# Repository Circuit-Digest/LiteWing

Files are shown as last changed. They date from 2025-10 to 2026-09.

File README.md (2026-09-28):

## LiteWing
image_tooltip
LiteWing is a compact, WiFi-controlled drone based on the ESP32-S3 microcontroller. Designed for hobbyists, makers, and engineers, LiteWing offers a simple yet powerful platform for drone experimentation and development. It is an open-hardware project, making it easy to modify and expand. Whether you're new to drones or an experienced developer looking to create custom flight applications, LiteWing provides an accessible and affordable way to explore drone technology. Unlike traditional drones that require proprietary controllers, LiteWing connects to your smartphone, allowing for an intuitive flying experience without additional hardware.

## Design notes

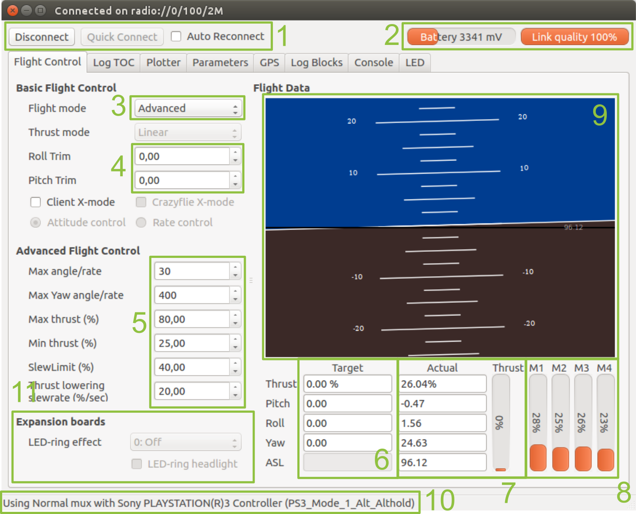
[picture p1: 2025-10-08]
Python-Scripts/crazyflie-clients-python/docs/images/cfclient_overview.png

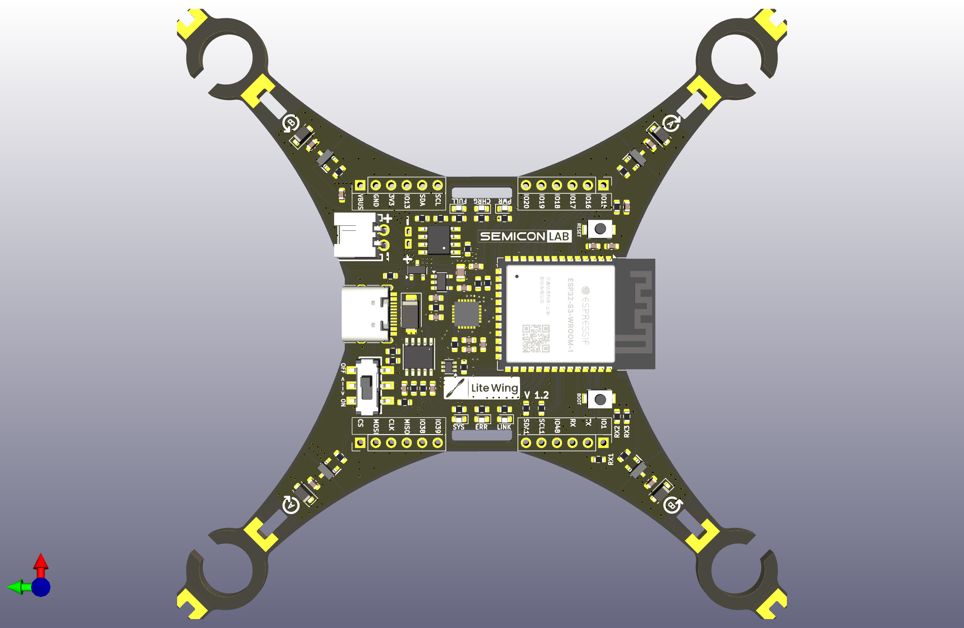
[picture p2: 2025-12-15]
hardware/LieWingV2.6.C/LieWingV2.6.C Front.png

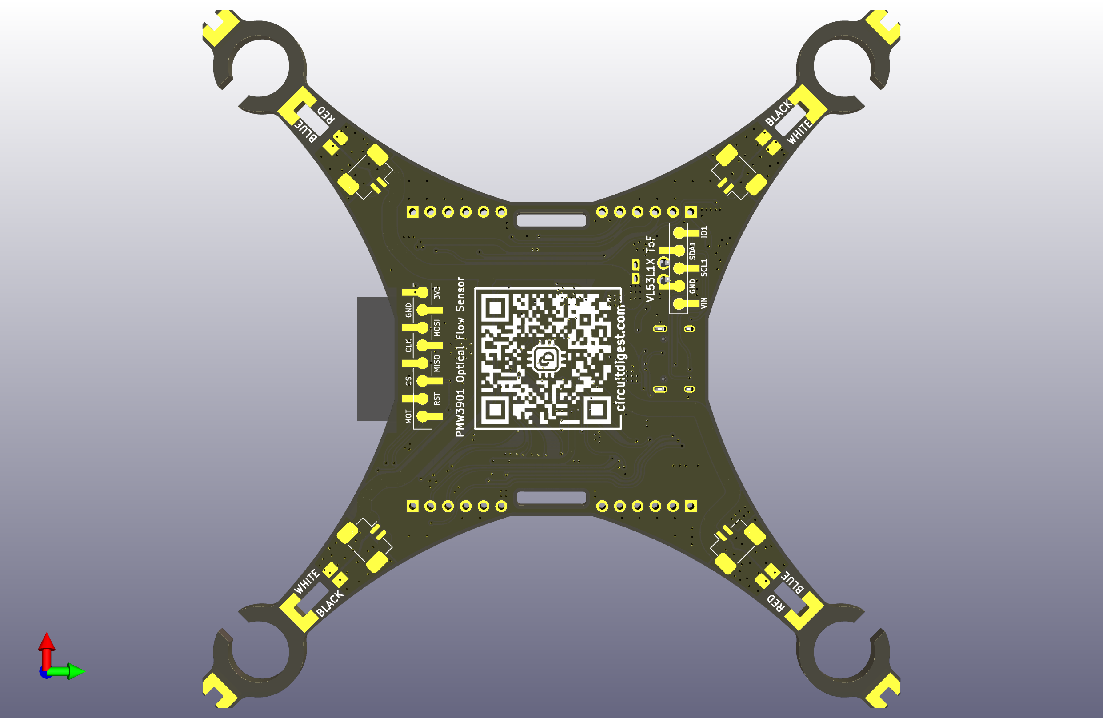
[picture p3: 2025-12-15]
hardware/LieWingV2.6.C/LieWingV2.6.C Back.png

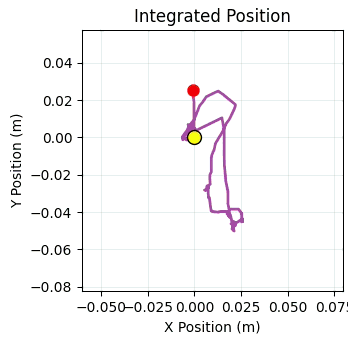
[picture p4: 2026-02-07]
Python-Scripts/Flight_Positioning_Module/LiteWing-Drone-Flight-Positioning-Module-Optical-Position-Plot.gif

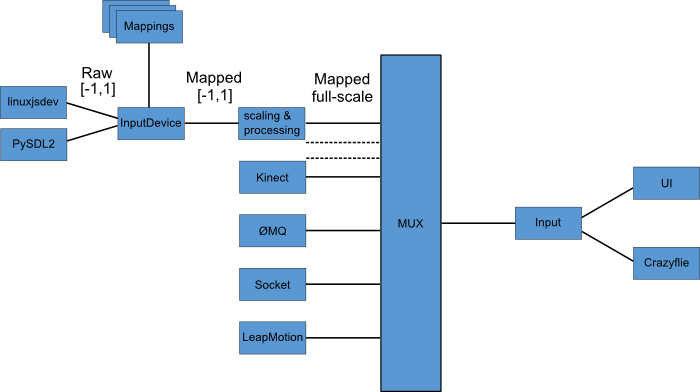
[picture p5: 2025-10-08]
Python-Scripts/crazyflie-clients-python/docs/images/input-arch-mux.png

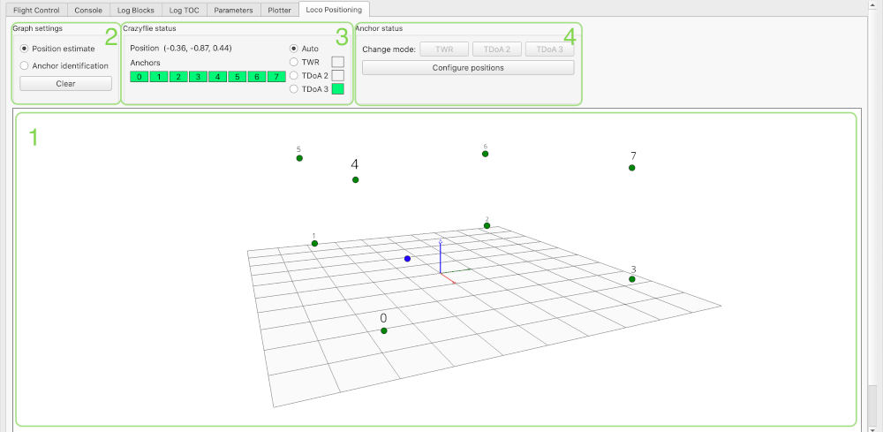
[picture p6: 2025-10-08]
Python-Scripts/crazyflie-clients-python/docs/images/cfclient_position_estimate.png

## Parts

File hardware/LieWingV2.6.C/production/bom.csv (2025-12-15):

Designator | Footprint | Quantity | Value | LCSC Part #
C1, C12, C4, C5 | 0603 | 4 | 10uF | C19702
C10, C13, C14, C6, C7, C8 | 0603 | 6 | 100nF | C14663
C11 | 0603 | 1 | 10nf | C57112
C15, C16, C17, C18 | 0603 | 4 | 1uF | C15849
C2 | 0603 | 1 | 470pF | C1620
C3 | 0805 | 1 | 2.2uF | C5448893
C9 | 0603 | 1 | 2.2nf | C1604
D1 | D_SMA | 1 | SS34 | C8678
D2, D3, D4, D5 | D_SOD-123F | 4 | 1N4148W | C81598
IC1 | SOIC127P600X175-9N | 1 | TP4056 | C20199357
J1 | USB_C_Receptacle_HRO_TYPE-C-31-M-12 | 1 | USB_C_Receptacle_USB2.0 | C2927038
J2 | CONN-TH_2P-P2.50_XH-2AW | 1 | JST XH 2P 2.50mm SMD Hoz | C33132
LED1, LED2, LED5 | 0603 | 3 | LED_Red | C2286
LED3, LED6 | 0603 | 2 | LED_Blue | C2288
LED4 | 0603 | 1 | LED_Green | C12065
R1, R2 | 0603 | 2 | 5.1K | C23186
R10, R11, R12, R13, R6, R7, R9 | 0603 | 7 | 1K | C21190
R14, R16, R17, R18, R19, R20, R21, R22, R23, R24, R25 | 0603 | 11 | 10k | C25804
R15 | 0603 | 1 | 4.7k | C23162
R26, R27, R3, R8 | 0603 | 4 | 100K | C25803
R28, R29, R30 | 0603 | 3 | 0R | C21189
R4 | 0603 | 1 | 470R | C23179
R5 | 0603 | 1 | 1.2K | C22765
SW1 | SW-SMD_MST22D18G2 | 1 | MST22D18G2_125 | C2906280
SW2, SW3 | Tactile 3x4x2mm TS-A010 | 2 | Tactile Switch 3x4x2 | C2874433
T1, T2, T3, T4 | SOT95P237X112-3N | 4 | IRLML6344TRPBF | C6285738
U1 | SOT-23 | 1 | AO3401A | C15127
U2 | SOT-23-5 | 1 | SPX3819M5-L-3-3/TR | C9055
U5 | ESSOP-10_3.9x4.9mm_P1.00mm | 1 | CH340K | C18208922
U6 | SOT-363_SC-70-6 | 1 | 2N27002DW | C5190214
U7 | MPU6050 | 1 | MPU-6050 | C24112
U8 | ESP32-S3-WROOM-1 | 1 | ESP32-S3-WROOM-1 | C2913198

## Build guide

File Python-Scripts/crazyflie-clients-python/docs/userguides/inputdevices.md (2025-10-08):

---
title: Input-devices for the Crazyflie client
page_id: inputdevices
---

The Crazyflie graphical control client needs an input-device (joystick)
with a minimum of 4 analogue axes to be able to pilot the Crazyflie. The
Playstation 3 controller is supported out of the box but the application
supports creating new configurations that uses other controllers. This
page details what controllers are supported out of the box, how to
create a new configurations and how to debug problems.

---

## Steps to get the controller working

Here\'s a few steps that you have to go though in order to get the
input-device working. If any of the steps are not working then the
input-device will not be usable for piloting the Crazyflie:

-   The input-device needs to be recognized by the host operating
    system. This means that it should be seen in the operating system
    and be usable in other applications or utilities.
-   When using the Crazyflie graphical control client you need at least
    the correct mappings for roll/pitch/yaw/thrust. This can be checked
    by opening the *Flight Data* tab. If the input-device is found and
    opened then you should see values in the *Target* fields for
    *Roll*,*Pitch*,*Yaw* and *Thrust*. Moving the analogue axis should
    show you output here. Make sure that you get the full span according
    to the settings on the left side of the tab. I.e if the setting for
    *Max roll/pitch* is 20 then you should be able to get from -20 to +
    20 in the target field (and the same for yaw and thrust). Also make
    sure that none of the axis interact (like moving roll will also move
    pitch).
-   If you aren\'t getting any output at all and you are using the
    Playstation 3 controller, then press the \"Playstation\" button in
    the middle on the controller once.
-   If the mappings are not correct in the previous point go to the menu
    *Input-device-\>Configure device mapping*, select the device you
    would like to configure and go though the configuration by clicking
    detect on each of the items in the dialog (everything has to be
    configured). Lastly enter the name of the configuration (without
    file extension) and press save. Now restart the application and try
    again.
-   It can happen be that another USB device other than your controller is recognized. Then it might be necessary to blacklist the USB device in the cfclient's config.json file. Check out [the config file explanation](/docs/development/dev_info_client.md#user-configuration-file)

---

## Input device overview

Below is a list of controllers and the status for different OSs. The
list is far from complete so if you have more info please edit or drop
us an email.

 | **Controller**    | **Linux USB** |   **Linux BT** |**Win XP USB**  | **Win XP BT**  |**Win7 USB**     |   **Win7 BT** |  **Win8 USB** |**Win10 USB** | **Win 11 USB** | **Mac OSX USB**  | **Mac OSX BT**|
|--|--|--|--|--|--|--|--|--|--|--|--|
 | Playstation 3 (or copy)  | Works  | Works |  Works |  Works | Works  | Works  | Works,  | Works | Not tested | Works   |  Works|
  Xbox 360 (or copy)   |  Works  | N/A  | Works    |   N/A    |   Works    |    N/A  |  Works | Works | Works| Not tested    |  Not tested|

### Playstation 3 controller

#### Linux using Bluetooth

[How to set up Sixaxis on
Ubuntu](https://help.ubuntu.com/community/Sixaxis) (tested on Ubuntu
13.10)

#### Win7 using USB

There\'s support for this using MotionJoy, **but** the mapping of the
axis is not the same as for Windows XP/Linux and has to be configured.
**TODO** Insert instructions for re-mapping.

[Video on how to get started with
MotionJoy](http://youtu.be/b2lUxNShIDs).

#### Win7 using Bluetooth

Should work using MotionJoy but this needs confirmation.

#### Win8 USB
[Instructions](http://www.wikihow.com/Set-Up-USB-Game-Controllers-on-Windows-8)

#### Mac OSX with Bluetooth

To pair the controller follow the steps outlined
[here](https://gist.github.com/statico/3172711). **TODO**: This
procedure is somewhat shaky. Figure out and add a solid set of steps
here.

**NOTE**: To shut down the controller you need to disconnect the
controller from OSX. This is easiest done if you enable in in System
Preferences -\> Bluetooth enable Show Bluetooth status in menu bar. From
the menu bar item you can easily disconnect it.

---

### Xbox 360 controller

#### Linux using USB

**INFO:** All modern Linux distribution now have a kernel driver for the x-box
gamepad. Thus it is unlikely the *xboxdrv* user-space driver is needed.

If you are having problems getting this to work the userspace driver
`xboxdrv` might be needed. It can be installed (on Ubuntu) by running:

    sudo apt-get install xboxdrv

And then started by running:

    sudo xboxdrv

More info about the `xboxdrv` is available
[here](https://xboxdrv.gitlab.io/).

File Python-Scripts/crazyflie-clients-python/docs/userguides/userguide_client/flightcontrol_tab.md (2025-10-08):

---
title: Flightcontrol Tab
page_id: flightcontrol_tab
sort_order: 1
---

The normal view used when flying is the one seen below.

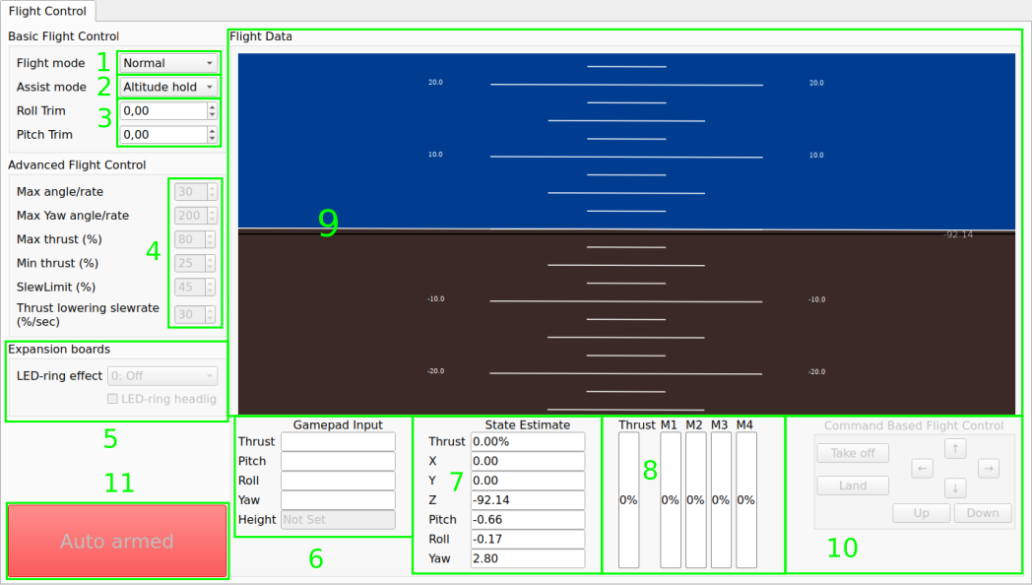
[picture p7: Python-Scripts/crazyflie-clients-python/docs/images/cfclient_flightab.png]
cfclient flighttab


1.  Flight mode selector (Normal and Advanced)
    * *Normal:* Recommended for beginners
    * *Advanced:* Will unlock flight settings in 3

2.  Assisted mode selection. The assisted mode is enabled when the assisted mode
    button is pressed on the Gamepad.
    * *Altitude hold*: Keeps the Crazyflie at its current altitude automatically. Thrust control becomes height velocity control.
    * *Position hold*: Keeps the Crazyflie at its current 3D position. Pitch/Roll/Thrust control becomes X/Y/Z velocity control.
    * *Height hold*: When activated, keeps the Crazyflie at 40cm above the ground. Thrust control becomes height velocity control. Requires a height sensor like the [Z-Ranger deck](https://www.bitcraze.io/products/z-ranger-deck-v2/).
    * *Hover*: When activated, keeps the Crazyflie at 40cm above the ground and tries to
    keep the position in X and Y as well. Thrust control becomes height velocity
    control. Requires a flow deck. Uses body-fixed coordinates.
3. Roll/pitch trim can be set either in the UI or using the controller (if the correct buttons are mapped).
    This will offset the input to the Crazyflie for correcting imbalance and reducing drift.
4. Advanced flight control settings are available if Advanced mode has been selected (settings are in %):
    * *Max angle:* Set the max roll/pitch angle allowed
    * *Max yaw rate:*Set the max yaw rate allowed
    * *Max thrust:* Set the max thrust allowed
    * *Min thrust:* Minimum thrust before 0 is sent to the Crazyflie
    * *Slew limit:* Set the percentage where the thrust is slew controlled (the thrust value lowering will be limited). This makes the Crazyflie a bit easier to fly for beginners
    * *Slew rate:* When the thrust is below the slew limit, this is the maximum rate of lowering the thrust
5. Settings for flight decks, currently the LED-ring effect and headlights can be set (if the ring is attached)
6. Target values sent from the client for controlling the Crazyflie
7. Actual values logged from the Crazyflie
8. Motor output on the Crazyflie
9. Horizon indicator
10. Command based flight control, allow controlled flight if, and only if, a positioning deck such as the [Flow deck](https://store.bitcraze.io/collections/decks/products/flow-deck-v2), the [Loco deck](https://store.bitcraze.io/collections/decks/products/loco-positioning-deck) or the [Lighthouse deck](https://store.bitcraze.io/collections/decks/products/lighthouse-positioning-deck) is present.
11. Arming/disarming button. Pressing this will send a arming or disarming event to the Crazyflie which will arm or disarm the system if this is possible. This button can also say "Auto arming" which indicates the crazyflie is configured to arm the system automatically if system checks have passed. More info in [crazyflie firmware arming documentation](https://www.bitcraze.io/documentation/repository/crazyflie-firmware/master/functional-areas/supervisor/arming/).

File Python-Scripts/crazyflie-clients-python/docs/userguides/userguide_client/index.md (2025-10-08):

---
title: Userguide cfclient GUI
page_id: userguide_client
sort_order: 1
---

This page is intended to give an overview on how to use the Crazyflie
client, not for installing it. For install instructions go
[here](https://github.com/bitcraze/crazyflie-clients-python/blob/develop/README.md).

The Crazyflie client is used for controlling the Crazyflie, flashing
firmware, setting parameters and logging data. The main UI is built up
of a number of [tabs](index.md#tabs-and-toolboxes), where each tab is used for a specific
functionality.

This page uses the terms
[roll/pitch/yaw](http://en.wikipedia.org/wiki/Flight_dynamics_(fixed_wing_aircraft))
extensively. For that to make any sense for a quadcopter we need to know
where the front is, so you will need to know [Crazyflie's coordinate system](https://www.bitcraze.io/documentation/system/platform/cf2-coordinate-system/)

---

## How to get flying with a controller

-   Start up the application
-   Insert the joystick and Crazyradio (PA)
-   Before you connect to the Crazyflie make sure that the joystick is
    working as expected and that the **thrust is zero**. The joystick
    values should be visible in the flight data box under target.
-   Press *Scan*
-   Wait for the scanning to complete
-   In the drop-down menu to the left of the Connect button select the
    Crazyflie you want to connect to. Connect to the URI e.g.
    radio://0/80/250k.
-   The client will now connect to the Crazyflie and handshake
-   When the handshake is done you can start flying the Crazyflie.
    Remember the most tricky part is the thrust so start out easy\...

For more info on LED indicators etc. have a look at the [Crazyflie 2.0 and Crazyflie 2.1(+) getting started guide](https://www.bitcraze.io/documentation/tutorials/getting-started-with-crazyflie-2-x/#understanding-leds) user guide.

---

## Main UI

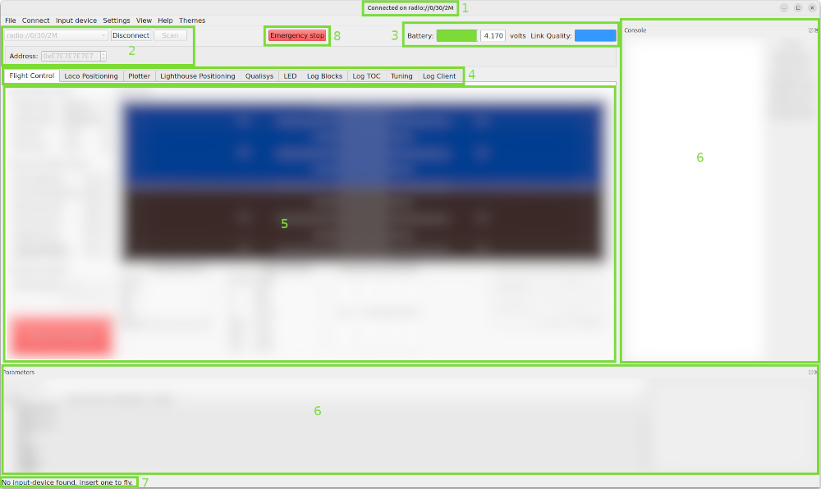
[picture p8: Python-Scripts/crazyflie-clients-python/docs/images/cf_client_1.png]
CF client main


1.  The window title will show the connection status
2.  Connect/disconnect, scan and the drop-down connection list as well
    as Address and auto reconnect.
       * *Scan:* Will scan for availible Crazyflies within the chosen address.
       * *Connect:* Will connect to the selected URI in the connection list
       * *Disconnect:* Will disconnect the current Crazyflie
       * *Address:* The address to scan for. If you didn't change this [in the configuration]( #firmware-configuration), then leave the default of 0xE7E7E7E7E7
3. Battery and link quality (from 0% to 100%)
4. Tabs with specific functionality (see below for details)
5. The content for the active tab
6. Toolboxes can be docked to the edges, making their content visible all the time.
7. The selected and used input interface
8. Emergency stop button. The motors will stop when clicked.

### Tabs and toolboxes

The main interface is built up of different tabs that can be shown/hidden from the *View-\>Tabs* menu. The tabs can
also be used as toolboxes, that is small windows that can be docked to the sides of the main window. This makes it possible
to display multiple windows at the same time, the console log can for instance be visible as a toolbox at the same time
as the parameter tab is open to set a value. To open a toolbox, use the *View-\>Toolboxes* menu, if the toolbox is
already open as a tab, the tab will be removed and it will be opened as a toolbox instead.

The following tabs/toolboxes are currently available:

{% sub_page_menu %}
---

## Functionality

Below are a few guides on how to accomplish specific tasks with the
client.

### Firmware upgrade

For updating the Crazyflie firmware you can keep being connected to the crazyflie. This will open up a separate dialog
that will guide you through the process.

Please note that you need to use a Crazyradio dongle to connect to the Crazyflie when doing firmware upgrades.
Upgrading using USB is **not** possible.

#### Deck firmware

Some decks have a CPUs or other chips that runs firmware that needs to be updated from time to time as well. The Crazyflie
firmware verifies that it is compatible with the deck firmware during start up. If the firmware in a deck that is
installed needs to be upgraded this will be logged in the console log. Deck firmware is upgraded as a part of the
Crazyflie firmware upgrade process, just make sure the deck is mounted when you run the upgrade.

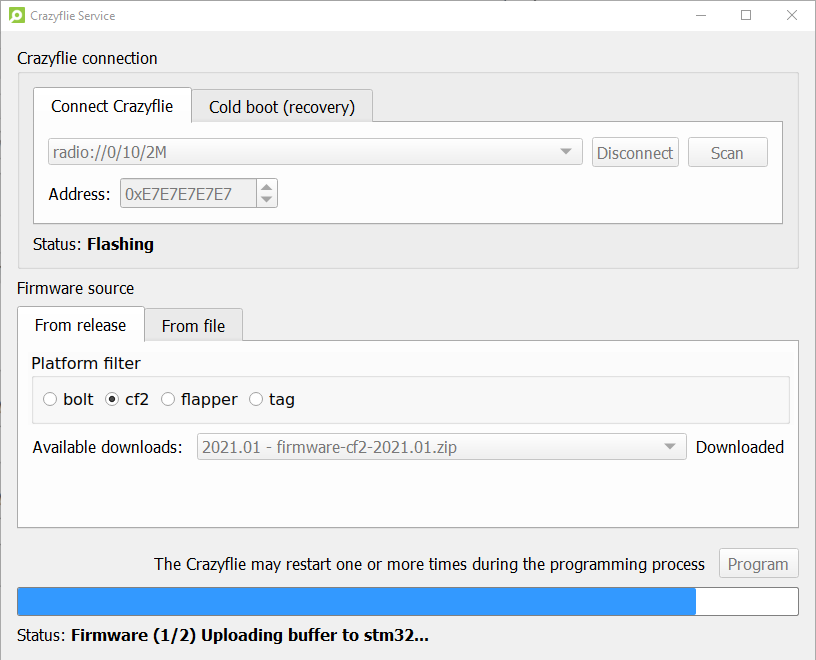
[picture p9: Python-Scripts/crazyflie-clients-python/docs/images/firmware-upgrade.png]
CFclient bootloading


To update the firmware in the Crazyflie 2.x do the following:

-   Make sure to have any decks you will be using attached during the update, since some of
the decks contain their own firmware which will also be updated during the firmware update. Also make sure there is a battery attached.
-   Go to the menu *Connect-\>Bootloader*
-   Connect to the crazyflie in this dialog, if it is not already connected in the flighttab.
-   Chose what to flash
    - Use the "From release" tab to automatically use an [official release](https://github.com/bitcraze/crazyflie-release/releases). Make sure to select the right platform (cf2 is the Crazyflie 2.x)
    - Use the "From file" tab if you have some other release file you want to flash.
-   Click \"Program\" and wait for both the STM, NRF and decks to be flashed. Note: the Crazyflie may restart multiple times during this process.
-   Your crazyflie will automatically restart a couple of times.
-   Do not touch or restart your crazyflie untill all flashing is done and you see \"status: idle\" at the bottom.
- To check the firmware version, under the *View* menu, open up *Tabs-\>Console* tab and look at the output when connecting to the
Crazyflie 2.x.

If you accidently restarted your crazyflie during flashing or anything else happend which caused your crazyflie to not start up properly, follow [the instructions for recovery mode](/docs/userguides/recovery-mode.md).

### Firmware configuration

It is possible to set another channel to communicate with the Crazyflie 2.x. It can be wise to do this if there exist other wireless
networks that can interfere, especially WiFi. It is also possible to
permanently store the trim values for pitch and roll.

It is currently possible to change the following parameters which are
stored in a none volatile memory:

-   **Pitch trim** Can be programmed permanently with the trim values
    found to work good in the flight tab.
-   **Roll trim** Can be programmed permanently with the trim values
    found to work good in the flight tab.
-   **Radio channel** Can be set to anything between 0 and 125,
    correspond to a frequency from 2400MHz to 2525MHz. In most countries
    channel 0 to 80 is OK to use but this should be checked with you
    local regulations. If using 2M datarate, the copter channels should
    be 2 apart (2MHz).
-   **Radio bandwidth** This can set the radio bandwidth to 250k, 1M or
    2M. A lower bandwidth has longer range but has higher chance of
    collision. When used inside sometimes it is better to use 1M or 2M
    as it decreases the risk of collision with WiFi.
-   **Radio address** (advanced) will set the shock burst address used
    for communicating. Note that if you change this then you will have
    to set the address correctly in the connect dialog.

The procedure is described below and the parameters can be changed again
any time the same way.

First connect to the Crazyflie 2.x with the normal connect button. Then open "Connect->Configure 2.x" to reach the configure 2.x dialog

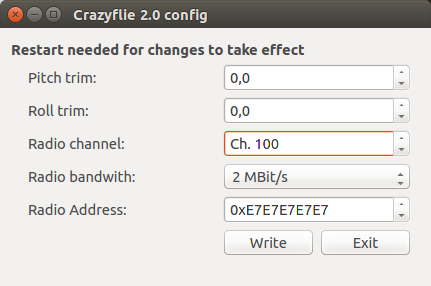
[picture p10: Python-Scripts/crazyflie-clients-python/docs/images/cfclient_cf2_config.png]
CF2 config


Once the settings has been made press the write button to save them permanently in the Crazyflie 2.x EEPROM.  Then restart the Crazyflie and connect to the new address.

### Logging

The Crazyflie logging framework allows to log the state of Crazyflie
variables in real-time. This subsystem is used by the client to show
information like pose or battery level.

The list of log variable can be seen in the \"log TOC\" tab in the
client.

Variables are logged in block: one log block is a list of variable that
are logged at the same time. You can setup custom log blocks that can be
plotted in the plotter and saved to file in the log block tab.

To setup a new log block click on the menu \"settings/logging
configuration\", You then see the following toolbox:

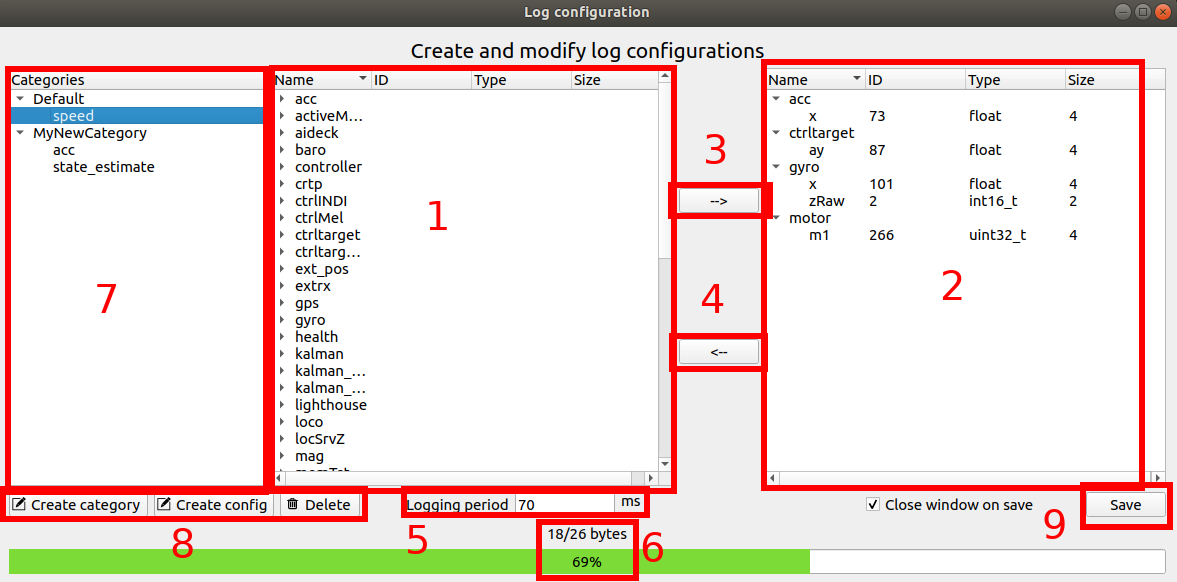
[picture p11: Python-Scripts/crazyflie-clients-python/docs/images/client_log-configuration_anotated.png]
cfclient logging configuration


1.  List of log variable in the Crazyflie
2.  Log variables in the current log block
3.  Add the selected Crazyflie log variable in the log block
4.  Remove the selected log block variable from the log block
5.  Period at which the variables are sampled and the block is send by
    the Crazyflie to the client. The minimum possible period is 10ms
    (100Hz) and it can be set by step of 10ms up to 2550ms.
6.  Bytes used by the variables in the log block.
7.  File-tree structure where you can sort the log-blocks into categories.
8.  Create/delete a category or a log-configuration. This can also
    be done by right-clicking anywhere in the category-tree.
9.  Save log block configuration

### Flight settings

By using the settings on the [Flight control tab](./flightcontrol_tab.md) you can set
things such as the max roll/pitch and thrust.

### Input devices

In order to control the Crazyflie you are connected to you will need
some input-device. Normally this would be a gamepad, but any
input-device with at least 4 analog axis will do. Here\'s
[a list](/docs/userguides/inputdevices.md) of some input-devices
that are used.

In order to make sense of the input from the device a mapping has to be
supplied. This mapping will convert raw axis values on the input-device
to useful values like roll/pitch/yaw/thrust. There\'s a few default
mappings shipped with the client, but it\'s easy to create your own.

### Creating new mappings

The software comes bundled with mappings for Xbox and PS3/4 controllers,
but if you have another input-device then it\'s quick to create your own
configuration. Go to the menu *Input device -\> Configure device
mapping*.

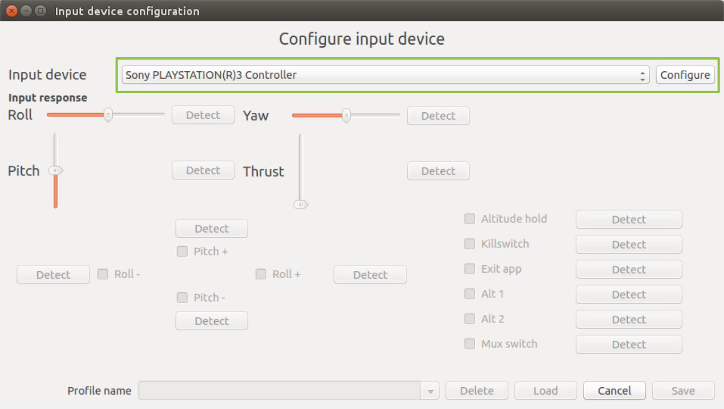
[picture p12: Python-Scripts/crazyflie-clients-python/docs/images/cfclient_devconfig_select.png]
cfclient configure device
{:align-center
width="700"}

Select the device you would like to configure and press *Configure*.

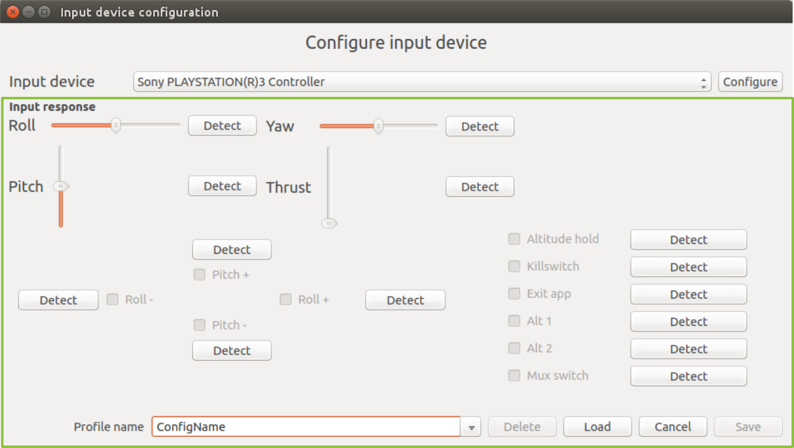
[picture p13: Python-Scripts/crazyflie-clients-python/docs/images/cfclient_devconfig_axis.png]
cfclient configure device axis
{:align-center
width="700"}

For each functionality that can be mapped there\'s a *Detect* button, by
pressing it the following dialog will appear.

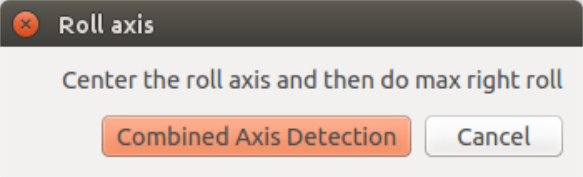
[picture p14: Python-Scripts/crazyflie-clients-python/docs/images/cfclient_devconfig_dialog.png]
cfclient configure device detect
{:align-center
width="300"}

Follow the instructions to detect the axis or button that you would like
to map to the functionality. If you would like to map the functionality
to two axis (like right/left shoulder-button) then select *Combined axis
detection* and follow the instructions.

Go though all the functionality you would like to map by pressing the
*Detect* button for each. To be able to save the mapping you will at
least have to map roll, pitch, yaw and thrust.

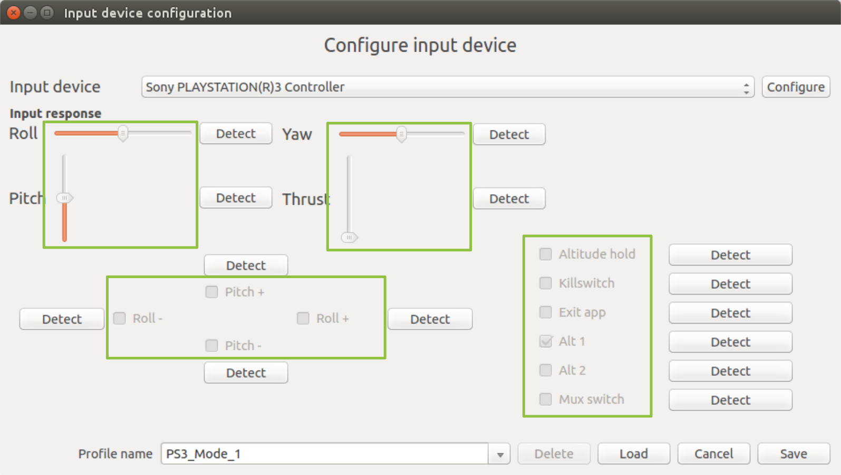
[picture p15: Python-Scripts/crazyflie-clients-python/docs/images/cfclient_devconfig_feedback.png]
cfclient configure device feedback
{:align-center
width="700"}

Once you have mapped functionality you will be able to see the feedback
directly in the configuration dialog (when you\'re not detecting a
button). Make sure to check that the response is what you intended. When
you are finished with the mapping then enter the map name and press
save.

If you would like to start from a previous configuration and change it
(either to update or to create a new one) then select the appropriate
mapping in the drop-down and press *Load*. Once you have made the
changes you would like to do then either press *Save* without changing
the name to update the mapping or enter a new name and press *Save* to
create a new one.

### Selecting device

The current input device and mapping can be selected from the *Input
device* menu.

The *Input device* menu contains a number of different \"modes\" that
can be used for controlling a Crazyflie. Currently there\'s thee to
choose from. The alternatives will only be enabled if there\'s enough
input devices connected to use them.

-   *Normal:* Just like it says this is the normal mode using only one
    controller to control a Crazyflie
-   *Teacher (RP):* This mode requires two input-devices, where one will
    be configured for roll and pitch and the other one for the rest of
    the functionality. By using the *Mux switch* functionality (mapped
    in the configuration) the second controller can take over roll and
    pitch as well
-   *Teacher (RPYT):* This mode requires two input-devices, where one
    will be configured for roll, pitch yaw and thrust, and the other one
    for the rest of the functionality. By using the *Mux switch*
    functionality (mapped in the configuration) the second controller
    can take over roll, pitch, yaw and thrust as well

For normal usage just enter the *Normal* menu, select the device you
would like to use and the correct mapping. As a device is selected the
list of mappings are enabled.

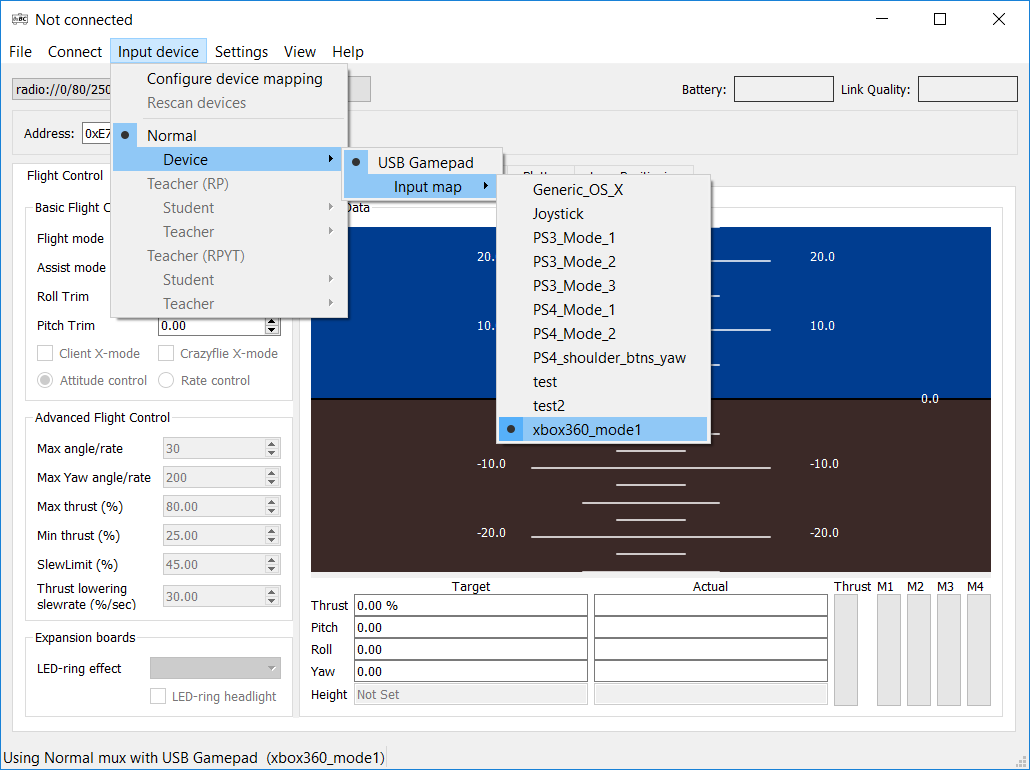
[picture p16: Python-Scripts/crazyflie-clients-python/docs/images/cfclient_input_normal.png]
cfclient devices normal
{:align-center
width="700"}

If more than one input device is connected then it\'s possible to switch
to one of the teacher modes.

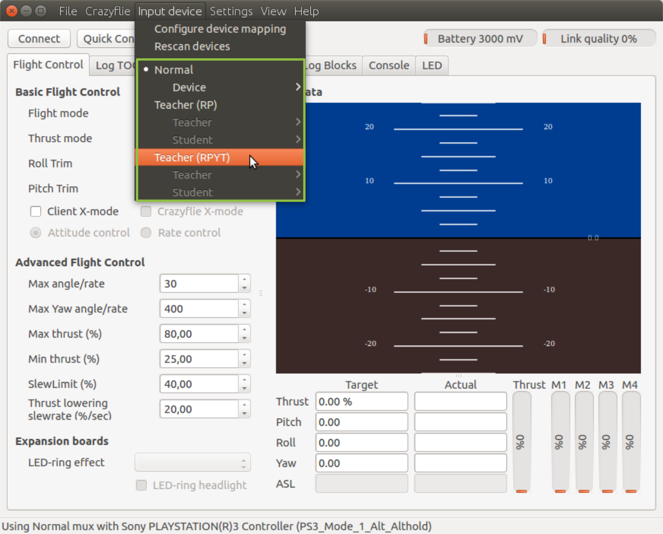
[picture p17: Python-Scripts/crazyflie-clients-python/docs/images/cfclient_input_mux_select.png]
cfclient devices mux select
{:align-center
width="700"}

First select the device that should be used for the teacher and then
it\'s mapping.

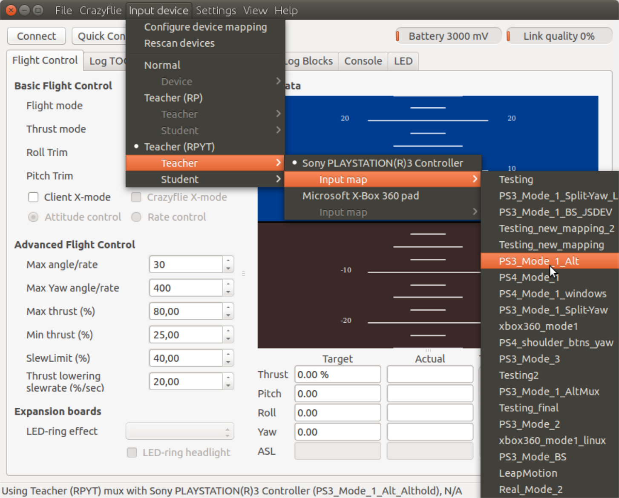
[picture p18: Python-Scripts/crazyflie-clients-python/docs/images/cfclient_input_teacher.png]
cfclient input teacher
{:align-center
width="700"}

Then select the device that should be used for the student and then
it\'s mapping.

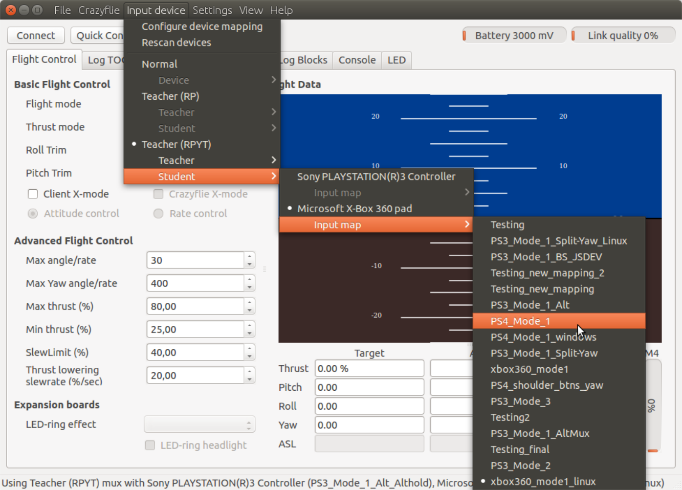
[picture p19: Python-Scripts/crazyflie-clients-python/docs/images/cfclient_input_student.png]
cfclient input student
{:align-center
width="700"}

Once this is done you will be able to see the open devices and
configurations at the bottom of the user interface.

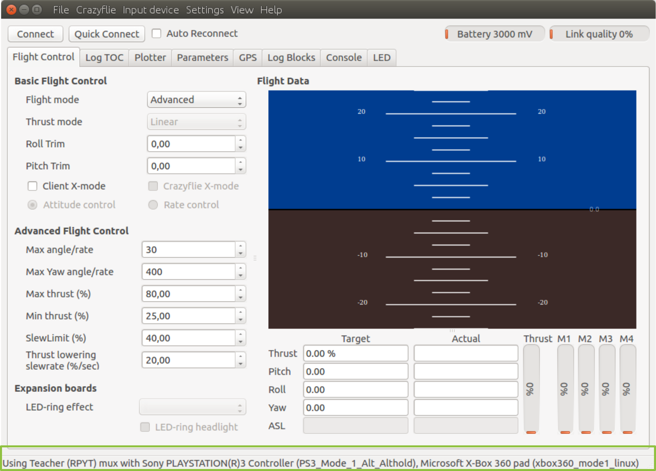
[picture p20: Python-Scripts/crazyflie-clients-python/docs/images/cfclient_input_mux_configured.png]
cfclient input mux configured
{:align-center
width="700"}

---

## ZMQ backends

The UI is normally used to get/set parameters, view logged data and send
control commands to the Crazyflie. Aside from this there\'s also the
possibility to connect via ZMQ to the client and control several things:

-   [Parameters](/docs/functional-areas/cfclient_zmq.md#parameters):
    Get/set parameters by name
-   [LED-ring memory](/docs/functional-areas/cfclient_zmq.md#led-ring):
    Write LED ring memory
-   [Input-device](/docs/functional-areas/cfclient_zmq.md#input-device):
    Act as an input device

The benefit of using this approach instead of the stand-alone ZMQ
server is that you will not have to
take care of everything, just the parts you are interested in for the
moment.

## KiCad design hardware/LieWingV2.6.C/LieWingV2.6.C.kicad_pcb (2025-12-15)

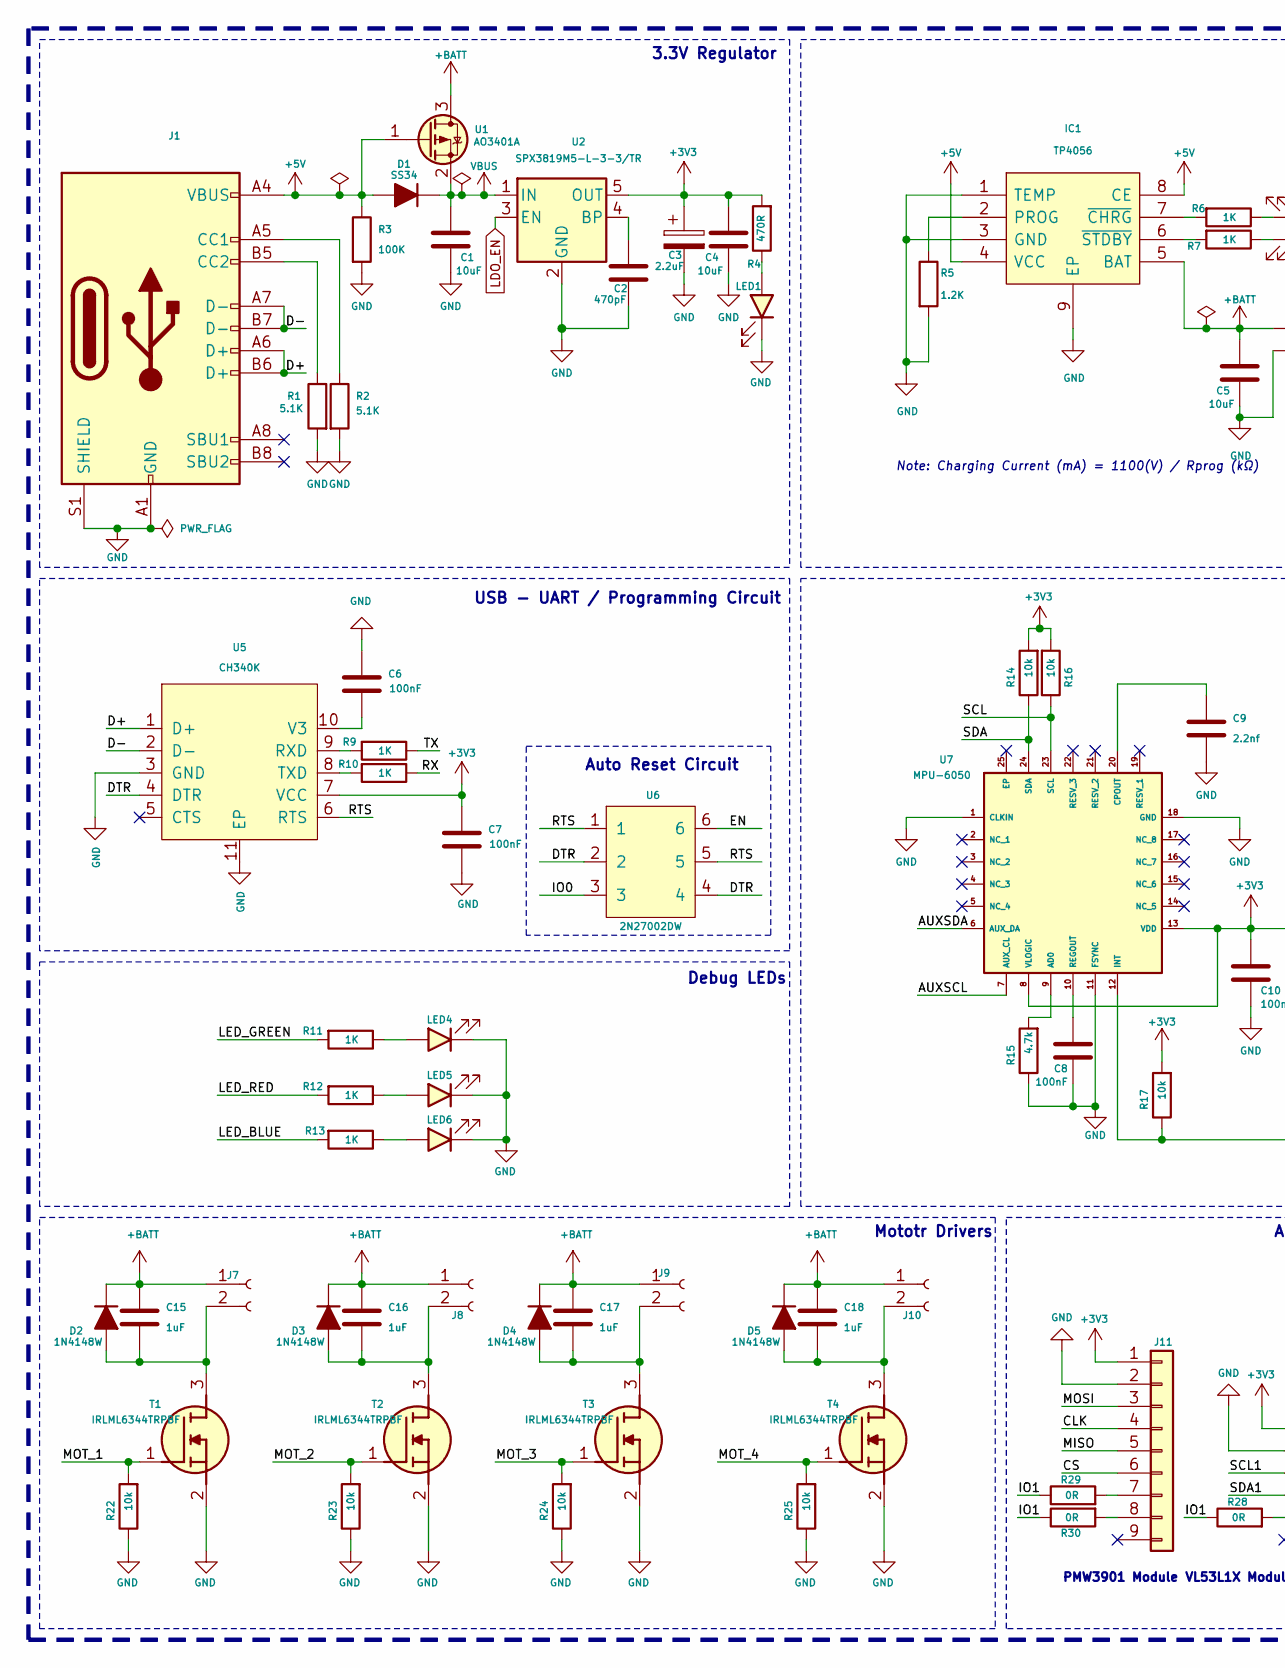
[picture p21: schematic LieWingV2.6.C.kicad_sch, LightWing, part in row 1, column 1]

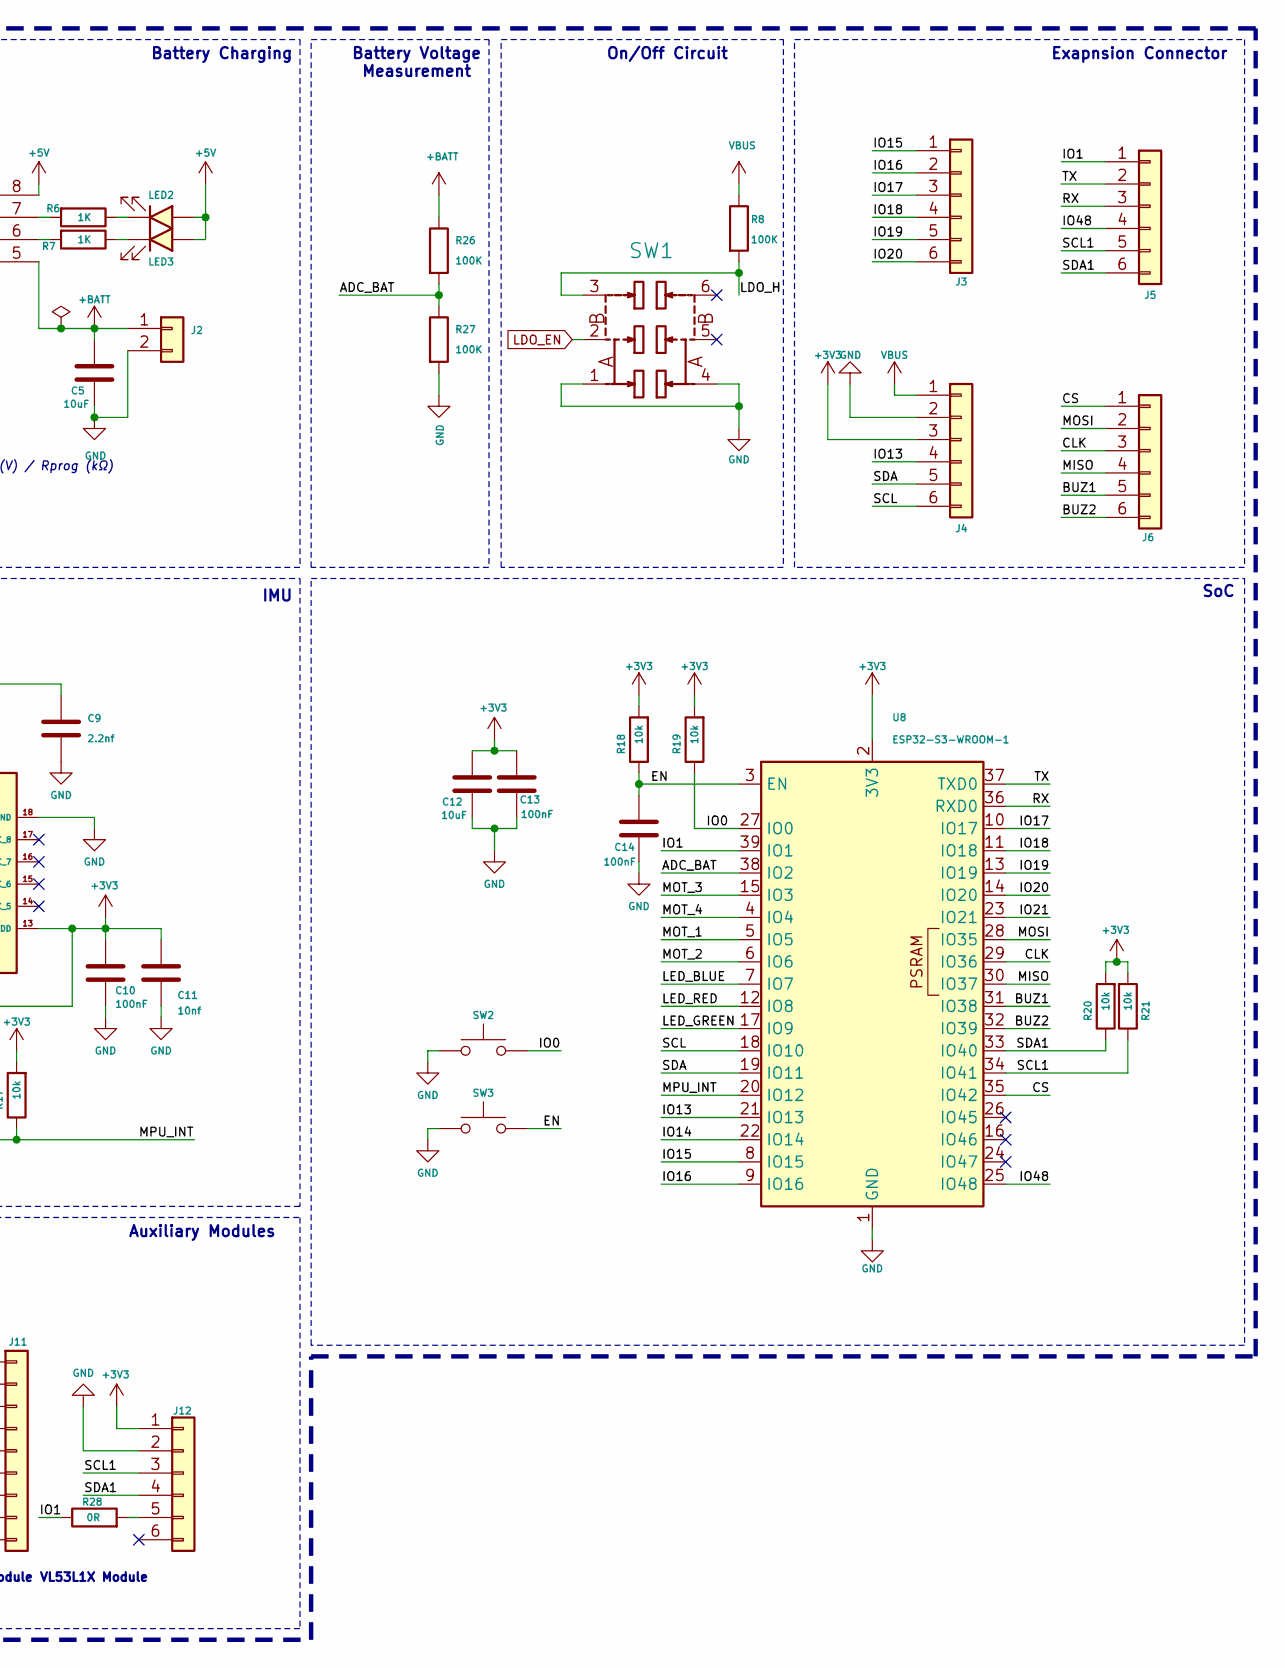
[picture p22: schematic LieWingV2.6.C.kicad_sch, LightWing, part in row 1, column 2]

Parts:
C1, C4, C5, C12: 10uF; C_0603_1608Metric; MFR.Part # CL10A106KP8NNNC; LCSC Part # C19702
C2: 470pF; C_0603_1608Metric; MFR.Part # 0603B471K500NT; LCSC Part # C1620
C3: 2.2uF; C_0805_2012Metric; MFR.Part # TCC0805X7R225M250FT; LCSC Part # C5448893
C6, C7, C8, C10, C13, C14: 100nF; C_0603_1608Metric; MFR.Part # CC0603KRX7R9BB104; LCSC Part # C14663
C9: 2.2nf; C_0603_1608Metric; MFR.Part # 0603B222K500NT; LCSC Part # C1604
C11: 10nf; C_0603_1608Metric; MFR.Part # 0603B103K500NT; LCSC Part # C57112
C15, C16, C17, C18: 1uF; C_0603_1608Metric; MFR.Part # CL10A105KB8NNNC; LCSC Part # C15849
D1: SS34; D_SMA; MFR.Part # SS34; LCSC Part # C8678
D2, D3, D4, D5: 1N4148W; D_SOD-123F; MFR.Part # 1N4148W; LCSC Part # C81598
IC1: TP4056; SOIC127P600X175-9N; MFR.Part # TP4056; LCSC Part # C20199357
J1: USB_C_Receptacle_USB2.0; USB_C_Receptacle_HRO_TYPE-C-31-M-12; MFR.Part # USB-TYPE-C-018; LCSC Part # C2927038
J2: JST XH 2P 2.50mm SMD Hoz; CONN-TH_2P-P2.50_XH-2AW; MFR.Part # XH-2AW; LCSC Part # C33132
J3, J4, J5, J6: Conn_01x06; PinHeader_1x06_P2.54mm_Vertical
J7, J8, J9, J10: Conn_01x02_Female; LiteWingMotor2
J11: Conn_01x09; PMW3901
J12: Conn_01x06; VL53L1X_BREAKOUT
LED1, LED2, LED5: LED_Red; LED_0603_1608Metric; MFR.Part # KT-0603R; LCSC Part # C2286
LED3, LED6: LED_Blue; LED_0603_1608Metric; MFR.Part # KT-0603B; LCSC Part # C2288
LED4: LED_Green; LED_0603_1608Metric; MFR.Part # LTST-C193TGKT-5A; LCSC Part # C12065
R1, R2: 5.1K; R_0603_1608Metric; MFR.Part # 0603WAF5101T5E; LCSC Part # C23186
R3, R8, R26, R27: 100K; R_0603_1608Metric; MFR.Part # 0603WAF1003T5E; LCSC Part # C25803
R4: 470R; R_0603_1608Metric; MFR.Part # 0603WAF4700T5E; LCSC Part # C23179
R5: 1.2K; R_0603_1608Metric; MFR.Part # 0603WAF1201T5E; LCSC Part # C22765
R6, R7, R9, R10, R11, R12, R13: 1K; R_0603_1608Metric; MFR.Part # 0603WAF1001T5E; LCSC Part # C21190
R14, R16, R17, R18, R19, R20, R21, R22, R23, R24, R25: 10k; R_0603_1608Metric; MFR.Part # 0603WAF1002T5E; LCSC Part # C25804
R15: 4.7k; R_0603_1608Metric; MFR.Part # 0603WAF4701T5E; LCSC Part # C23162
R28, R29, R30: 0R; R_0603_1608Metric; MFR.Part # 0603WAF0000T5E; LCSC Part # C21189
SW1: MST22D18G2_125; SW-SMD_MST22D18G2; MFR.Part # MST22D18G2 125; LCSC Part # C2906280
SW2, SW3: Tactile Switch 3x4x2; Tactile 3x4x2mm TS-A010; MFR.Part # TS-KG88C-ART25F; LCSC Part # C2874433
T1, T2, T3, T4: IRLML6344TRPBF; SOT95P237X112-3N; MFR.Part # IRLML6344TRPBF-HXY; LCSC Part # C6285738
U1: AO3401A; SOT-23; MFR.Part # AO3401A; LCSC Part # C15127
U2: SPX3819M5-L-3-3/TR; SOT-23-5; MFR.Part # SPX3819M5-L-3-3/TR; LCSC Part # C9055
U5: CH340K; ESSOP-10_3.9x4.9mm_P1.00mm; MFR.Part # CH340K; LCSC Part # C18208922
U6: 2N27002DW; SOT-363_SC-70-6; MFR.Part # 2N27002DW; LCSC Part # C5190214
U7: MPU-6050; MPU6050; MFR.Part # MPU-6050; LCSC Part # C24112
U8: ESP32-S3-WROOM-1; MFR.Part # ESP32-S3-WROOM-1-N8; LCSC Part # C2913198

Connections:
+3V3: C3.1, C4.1, C7.1, C10.1, C11.1, C12.1, C13.1, J4.3, J11.1, J12.1, R4.2, R14.2, R16.2, R17.2, R18.2, R19.2, R20.2, R21.2, U2.5 (OUT), U5.7 (VCC), U7.8 (VLOGIC), U7.13 (VDD), U8.2 (3V3)
+5V: D1.2 (A), IC1.4 (VCC), IC1.8 (CE), J1.A4 (VBUS), J1.A9 (VBUS), J1.B4 (VBUS), J1.B9 (VBUS), LED2.2 (A), LED3.2 (A), R3.1, U1.1 (G)
+BATT: C5.1, C15.1, C16.1, C17.1, C18.1, D2.1 (K), D3.1 (K), D4.1 (K), D5.1 (K), IC1.5 (BAT), J2.1, J7.1, J8.1, J9.1, J10.1, R26.1, U1.3 (D)
/ADC_BAT: R26.2, R27.1, U8.38 (IO2)
/AUXSCL: U7.7 (AUX_CL)
/AUXSDA: U7.6 (AUX_DA)
/BUZ1: J6.5, U8.31 (IO38)
/BUZ2: J6.6, U8.32 (IO39)
/CLK: J6.3, J11.4, U8.29 (IO36)
/CS: J6.1, J11.6, U8.35 (IO42)
/D+: J1.A6 (D+), J1.B6 (D+), U5.1 (D+)
/D-: J1.A7 (D-), J1.B7 (D-), U5.2 (D-)
/DTR: U5.4 (DTR), U6.2, U6.4
/EN: C14.1, R18.1, SW3.2, U6.6, U8.3 (EN)
/IO0: R19.1, SW2.2, U6.3, U8.27 (IO0)
/IO1: J5.1, R28.1, R29.1, R30.1, U8.39 (IO1)
/IO13: J4.4, U8.21 (IO13)
/IO14: U8.22 (IO14)
/IO15: J3.1, U8.8 (IO15)
/IO16: J3.2, U8.9 (IO16)
/IO17: J3.3, U8.10 (IO17)
/IO18: J3.4, U8.11 (IO18)
/IO19: J3.5, U8.13 (IO19)
/IO20: J3.6, U8.14 (IO20)
/IO21: U8.23 (IO21)
/IO48: J5.4, U8.25 (IO48)
/LDO_H: R8.2, SW1.3
/LED_BLUE: R13.2, U8.7 (IO7)
/LED_GREEN: R11.2, U8.17 (IO9)
/LED_RED: R12.2, U8.12 (IO8)
/MISO: J6.4, J11.5, U8.30 (IO37)
/MOSI: J6.2, J11.3, U8.28 (IO35)
/MOT_1: R22.2, T1.1 (G), U8.5 (IO5)
/MOT_2: R23.2, T2.1 (G), U8.6 (IO6)
/MOT_3: R24.2, T3.1 (G), U8.15 (IO3)
/MOT_4: R25.2, T4.1 (G), U8.4 (IO4)
/MPU_INT: R17.1, U7.12 (INT), U8.20 (IO12)
/RTS: U5.6 (RTS), U6.1, U6.5
/RX: J5.3, R10.1, U8.36 (RXD0)
/SCL: J4.6, R16.1, U7.23 (SCL), U8.18 (IO10)
/SCL1: J5.5, J12.3, R21.1, U8.34 (IO41)
/SDA: J4.5, R14.1, U7.24 (SDA), U8.19 (IO11)
/SDA1: J5.6, J12.4, R20.1, U8.33 (IO40)
/TX: J5.2, R9.1, U8.37 (TXD0)
GND: C1.2, C2.2, C3.2, C4.2, C5.2, C6.1, C7.2, C8.2, C9.2, C10.2, C11.2, C12.2, C13.2, C14.2, IC1.1 (TEMP), IC1.3 (GND), IC1.9 (EP), J1.A1 (GND), J1.A12 (GND), J1.B1 (GND), J1.B12 (GND), J1.S1 (SHIELD), J2.2, J4.2, J11.2, J12.2, LED1.1 (K), LED4.1 (K), LED5.1 (K), LED6.1 (K), R1.2, R2.2, R3.2, R5.2, R15.1, R22.1, R23.1, R24.1, R25.1, R27.2, SW1.1, SW1.4, SW2.1, SW3.1, T1.2 (S), T2.2 (S), T3.2 (S), T4.2 (S), U2.2 (GND), U5.3 (GND), U5.11 (EP), U7.1 (CLKIN), U7.11 (FSYNC), U7.18 (GND), U8.1 (GND), U8.40 (GND), U8.41 (GND)
LDO_EN: SW1.2, U2.3 (EN)
unnamed: C15.2, D2.2 (A), J7.2, T1.3 (D)
unnamed: C16.2, D3.2 (A), J8.2, T2.3 (D)
unnamed: C17.2, D4.2 (A), J9.2, T3.3 (D)
unnamed: C18.2, D5.2 (A), J10.2, T4.3 (D)
unnamed: IC1.2 (PROG), R5.1
unnamed: IC1.7 (~CHRG), R6.2
unnamed: IC1.6 (~STDBY), R7.2
unnamed: J1.A5 (CC1), R2.1
unnamed: J1.B5 (CC2), R1.1
unnamed: J11.7, R29.2
unnamed: J11.8, R30.2
unnamed: J12.5, R28.2
unnamed: LED1.2 (A), R4.1
unnamed: LED2.1 (K), R6.1
unnamed: LED3.1 (K), R7.1
unnamed: LED4.2 (A), R11.1
unnamed: LED5.2 (A), R12.1
unnamed: LED6.2 (A), R13.1
unnamed: C2.1, U2.4 (BP)
unnamed: R9.2, U5.9 (RXD)
unnamed: R10.2, U5.8 (TXD)
unnamed: C6.2, U5.10 (V3)
unnamed: R15.2, U7.9 (AD0)
unnamed: C9.1, U7.20 (CPOUT)
unnamed: C8.1, U7.10 (REGOUT)
VBUS: C1.1, D1.1 (K), J4.1, R8.1, U1.2 (S), U2.1 (IN)

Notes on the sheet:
Note: Charging Current (mA) = 1100(V) / Rprog (kΩ)
IMU
VL53L1X Module
Debug LEDs
Battery Charging
3.3V Regulator
Battery Voltage Measurement
Auto Reset Circuit
USB - UART / Programming Circuit
SoC
Mototr Drivers
Exapnsion Connector
Auxiliary Modules
On/Off Circuit
PMW3901 Module

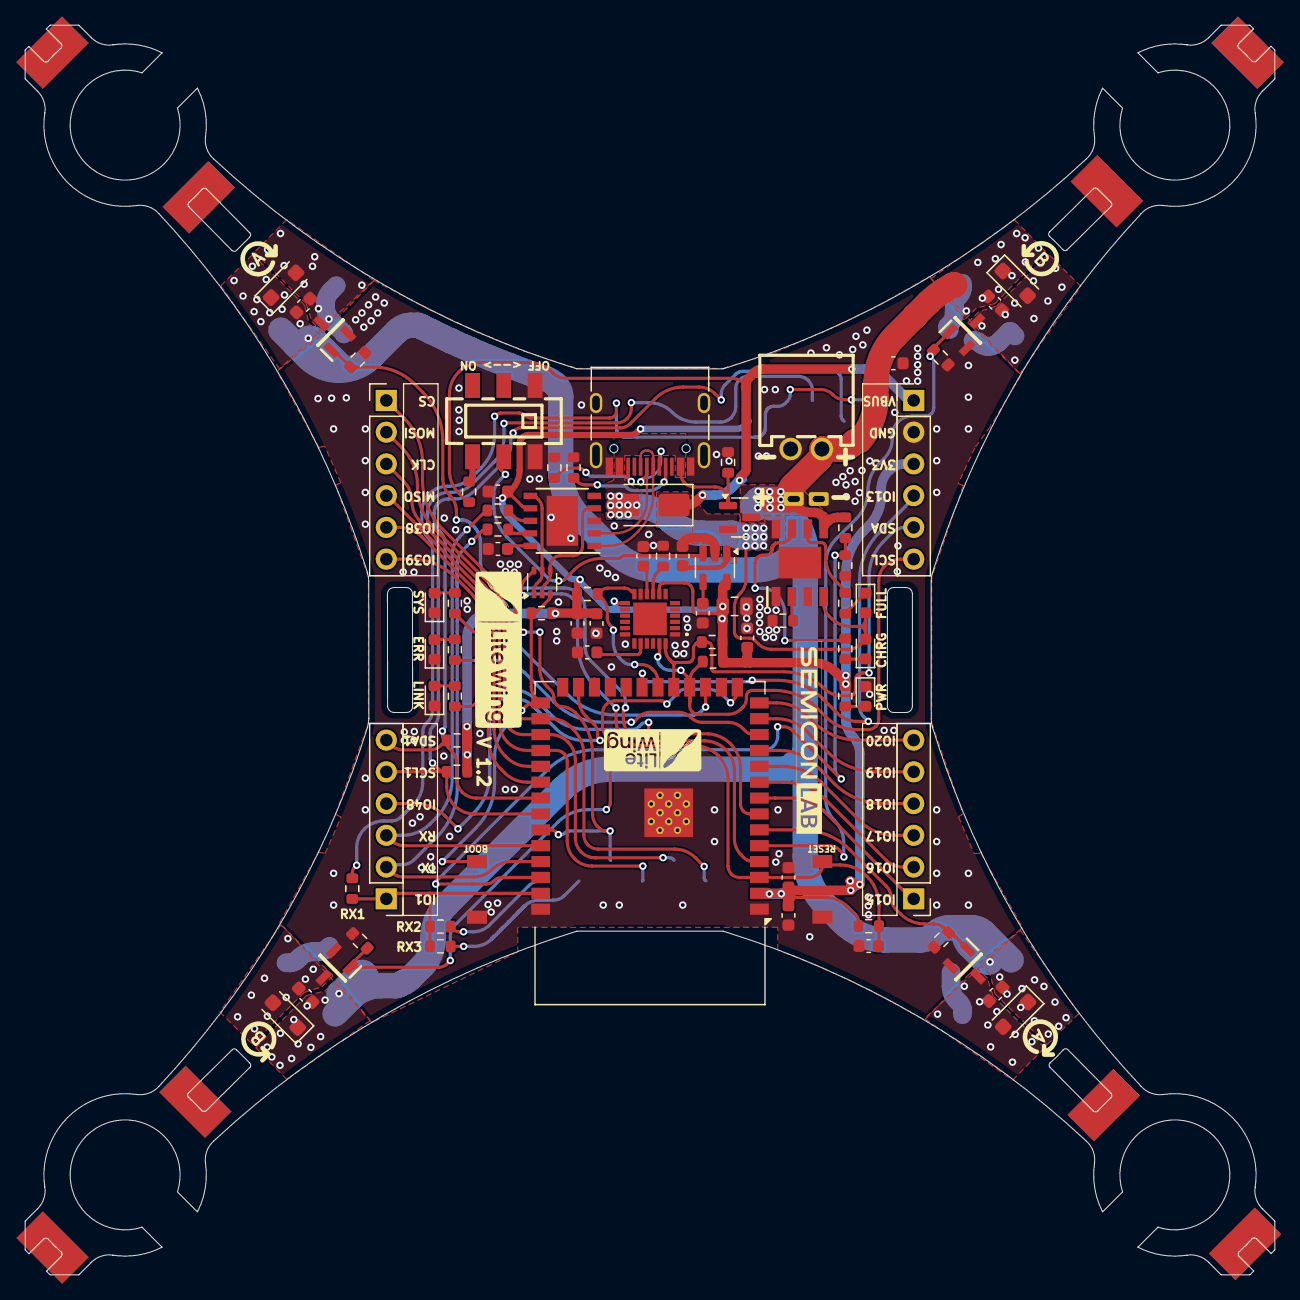
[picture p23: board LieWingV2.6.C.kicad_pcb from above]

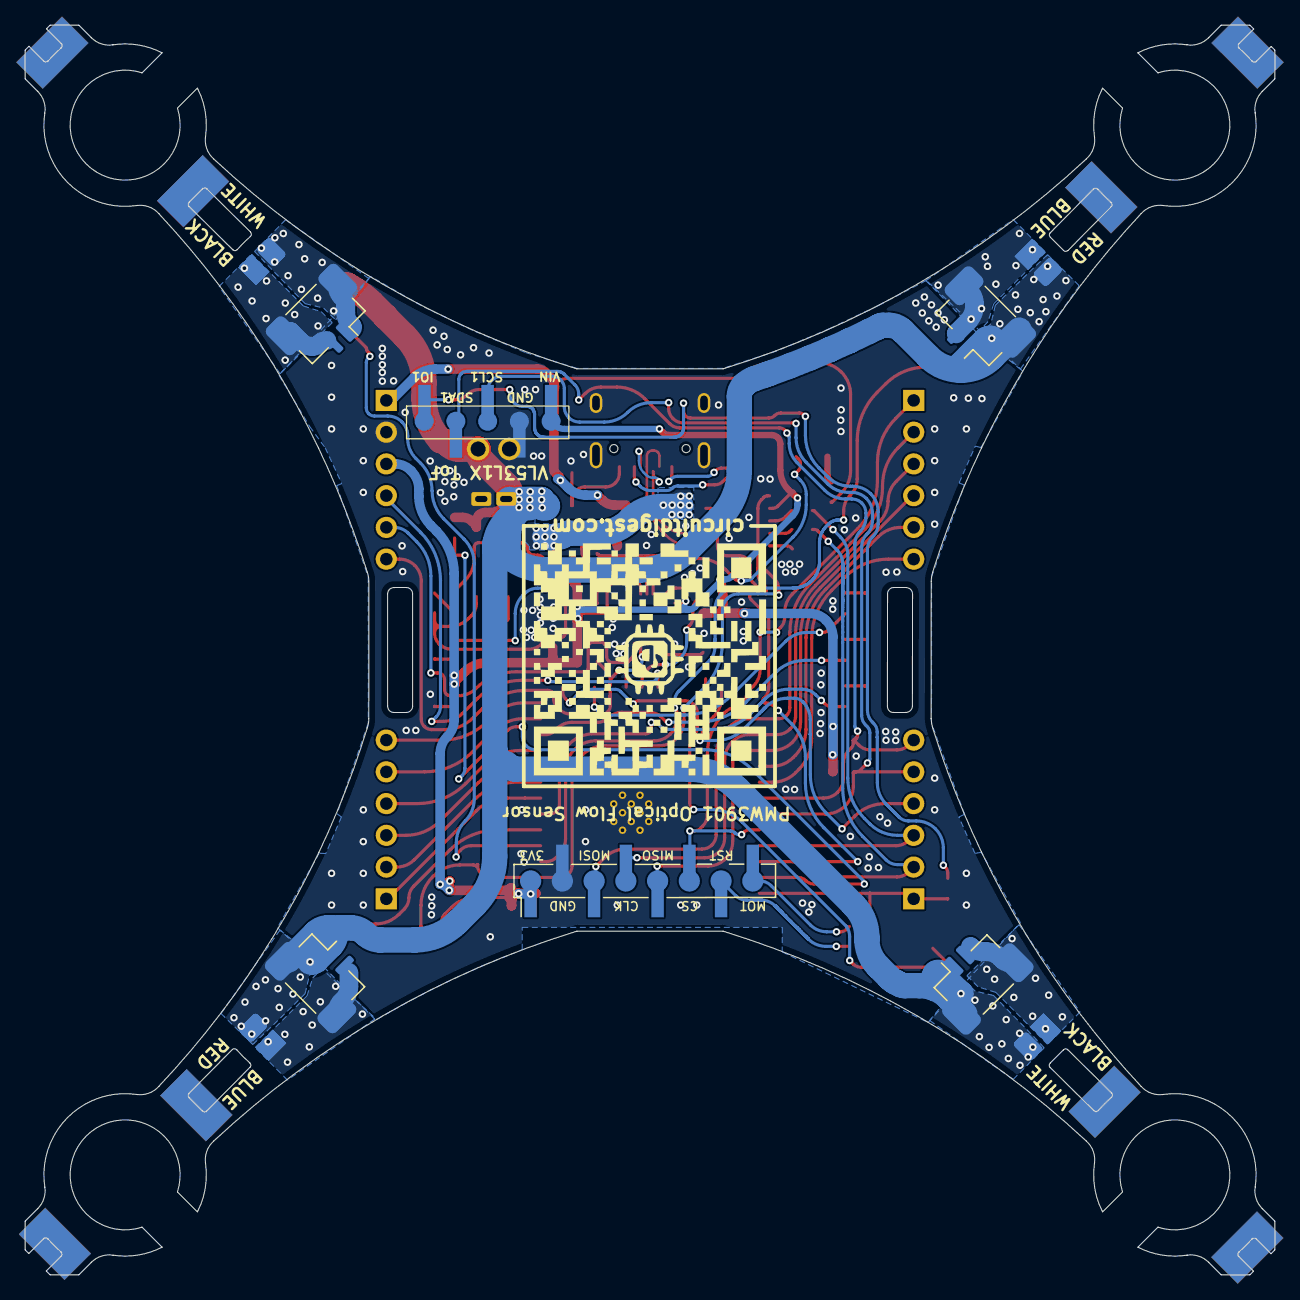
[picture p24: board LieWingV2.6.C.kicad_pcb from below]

Board: 2 copper layers, 100.0 x 100.0 mm, 85 parts (2 on the bottom side), 68 nets.

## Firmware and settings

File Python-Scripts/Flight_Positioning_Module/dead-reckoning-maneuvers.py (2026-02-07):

"""
Dead Reckoning Maneuvers - Full-Featured Control Script
========================================================
A comprehensive script for optical flow-based position hold with 
advanced maneuver capabilities. Uses dead reckoning with PID controllers 
to maintain the drone's position and execute directional maneuvers.

This script provides a full-featured GUI for controlling the drone with
real-time visualization of sensor data, position tracking, and various
control modes including manual joystick control and autonomous shapes.

Features:
- Sensor Test to arm/prepare the drone
- Optical flow-based position hold
- Adjustable TRIM values, Height, and PID parameters
- Real-time position, velocity, and correction feedback
- Safety checks for battery and sensors
- NeoPixel LED control for visual feedback
- Directional maneuvers (Forward, Backward, Left, Right)
- Autonomous shape execution
- Joystick control with multiple modes
- CSV data logging for flight analysis
- Real-time matplotlib plotting

Usage:
1. Connect to the drone via UDP
2. Click "Sensor Test" to arm and verify sensors
3. Adjust parameters if needed (TRIM, Height, PID)
4. Click "Start Position Hold" to takeoff and hover
5. Use directional buttons or joystick for maneuvers
6. The drone will maintain its position automatically
7. Click "Stop" or press Enter for emergency stop

Author: Dharageswaran S
Version: 1.0
"""

import time
import threading
import cflib.crtp
from cflib.crazyflie import Crazyflie
from cflib.crazyflie.log import LogConfig
from cflib.crazyflie.syncCrazyflie import SyncCrazyflie
import tkinter as tk
from tkinter import ttk
from matplotlib.backends.backend_tkagg import FigureCanvasTkAgg
from matplotlib.figure import Figure
import matplotlib.animation as animation
from matplotlib.pylab import f
import numpy as np
import csv
import math
from datetime import datetime
import os
from PIL import Image, ImageTk
from collections import deque
import threading


# === CONSTANTS ===
# CRTP and NeoPixel constants
CRTP_PORT_NEOPIXEL = 0x09
NEOPIXEL_CHANNEL_SET_PIXEL = 0x00
NEOPIXEL_CHANNEL_SHOW = 0x01
NEOPIXEL_CHANNEL_CLEAR = 0x02
NEOPIXEL_CHANNEL_BLINK = 0x03
NP_SEND_RETRIES = 3
NP_PACKET_DELAY = 0.02
NP_LINK_SETUP_DELAY = 0.12


# === CONFIGURATION PARAMETERS ===
DRONE_URI = "udp://192.168.43.42"
TARGET_HEIGHT = 0.3  # Target hover height in meters
TAKEOFF_TIME = 1.0  # Time to takeoff and stabilize (reduced for steeper ramp)
HOVER_DURATION = 20.0  # How long to hover with position hold
LANDING_TIME = 0.5  # Time to land
# Debug mode - set to True to disable motors (sensors and logging still work)
DEBUG_MODE = False
# Height sensor safety check - set to False to disable emergency stop during takeoff/stabilized
ENABLE_HEIGHT_SENSOR_SAFETY = False 
# Filtering strength for velocity smoothing (0.0 = no smoothing, 1.0 = max smoothing)
VELOCITY_SMOOTHING_ALPHA = 0.85  # Default: 0.7 (previously hardcoded)
# CSV Logging - set to False to disable CSV file generation
DRONE_CSV_LOGGING = False
# Takeoff Ramp - set to False to disable smooth altitude climb (direct target height)
ENABLE_TAKEOFF_RAMP = False

# Basic trim corrections
TRIM_VX = 0.0  # Forward/backward trim correction
TRIM_VY = 0.0  # Left/right trim correction
# Battery monitoring
LOW_BATTERY_THRESHOLD = 2.9  # Low battery warning threshold in volts
# Height sensor safety
HEIGHT_SENSOR_MIN_CHANGE = (
    0.005  # Minimum height change expected during takeoff (meters)
)

# === DEAD RECKONING POSITION CONTROL PARAMETERS ===
# PID Controller Parameters
# Start here, then increase gradually
POSITION_KP = 1.0
POSITION_KI = 0.03  # Increased from 0.01 for better drift correction
POSITION_KD = 0.0
VELOCITY_KP = 0.7   # Increased from 0.5 for better damping
VELOCITY_KI = 0.01
VELOCITY_KD = 0.0
# Control limits
MAX_CORRECTION = 0.7  # Maximum control correction allowed
VELOCITY_THRESHOLD = 0.005  # Consider drone "stationary" below this velocity
DRIFT_COMPENSATION_RATE = 0.004  # Gentle pull toward zero when moving slowly
# Position integration and reset
PERIODIC_RESET_INTERVAL = 90.0  # Reset integrated position every 5 seconds
MAX_POSITION_ERROR = 2.0  # Clamp position error to prevent runaway
# Sensor parameters
SENSOR_PERIOD_MS = 10  # Motion sensor update rate
DT = SENSOR_PERIOD_MS / 1000.0
CONTROL_UPDATE_RATE = 0.02  # 50Hz control loop
# Velocity calculation constants
DEG_TO_RAD = 3.1415926535 / 180.0
# Optical flow scaling - adjust these to match your sensor/setup
OPTICAL_FLOW_SCALE = (
    4.4  # Empirical scaling factor (adjust based on real vs measured distance)
)
USE_HEIGHT_SCALING = True  # Set to False to disable height dependency

# === MANEUVER PARAMETERS ===
MANEUVER_DISTANCE = 0.5  # Default distance
MANEUVER_THRESHOLD = 0.10  # Within 5cm is close enough
WAYPOINT_TIMEOUT = 60.0  # Seconds before aborting mission
WAYPOINT_STABILIZATION_TIME = 0.5  # Seconds to hover at each corner
JOYSTICK_SENSITIVITY = 0.2

# === JOYSTICK MOMENTUM COMPENSATION ===
# When keys are released in "Hold at Current Position" mode, these parameters help prevent counter-movement
MOMENTUM_COMPENSATION_TIME = (
    0.10  # Seconds of velocity to predict stopping position (0.05-0.15 recommended)
)
SETTLING_DURATION = (
    0.1  # Time to use gentler corrections after key release (0.1-0.3 seconds)
)
SETTLING_CORRECTION_FACTOR = (
    0.5  # Correction strength during settling period (0.3-0.7, lower = gentler)
)

# === FIRMWARE PARAMETERS (Z-AXIS) ===
# Set to True to send these values to the drone on connection
ENABLE_FIRMWARE_PARAMS = False
FW_THRUST_BASE = 24000  # Default: 24000. Increase if drone feels heavy (e.g., 26000)
FW_Z_POS_KP = 1.6        # Default: 1.6. Height position gain
FW_Z_VEL_KP = 15.0       # Default: 22.0. Vertical velocity damping (stop bouncing)

# === OUTPUT WINDOW LOG ===
Output_Window = True  # Set to True to enable output log window, False to disable

# === GLOBAL VARIABLES ===
# Sensor data
current_height = 0.0
current_range_height = 0.0
motion_delta_x = 0
motion_delta_y = 0
sensor_data_ready = False
last_sensor_heartbeat = time.time()  # Track last received packet
DATA_TIMEOUT_THRESHOLD = 0.2        # Max allowed time between sensor packets (seconds)
# Log file
log_file = None
log_writer = None
# Battery voltage data
current_battery_voltage = 0.0
battery_data_ready = False
# Velocity tracking
current_vx = 0.0
current_vy = 0.0
velocity_x_history = [0.0, 0.0]
velocity_y_history = [0.0, 0.0]
# Dead reckoning position integration
integrated_position_x = 0.0
integrated_position_y = 0.0
last_integration_time = time.time()
last_reset_time = time.time()
# Control corrections
current_correction_vx = 0.0
current_correction_vy = 0.0
# PID Controller state variables
position_integral_x = 0.0
position_integral_y = 0.0
position_derivative_x = 0.0
position_derivative_y = 0.0
last_position_error_x = 0.0
last_position_error_y = 0.0
velocity_integral_x = 0.0
velocity_integral_y = 0.0
velocity_derivative_x = 0.0
velocity_derivative_y = 0.0
last_velocity_error_x = 0.0
last_velocity_error_y = 0.0
# Flight state
flight_phase = "IDLE"
flight_active = False
sensor_test_active = False  # New variable for sensor test state
scf_instance = None
position_integration_enabled = False
# Maneuver state
maneuver_active = False
target_position_x = 0.0
target_position_y = 0.0
# Shape maneuver state
shape_active = False
shape_waypoints = []
shape_index = 0
waypoint_start_time = 0.0
# Data history for plotting
max_history_points = 300  # Increased for better visualization
time_history = deque(maxlen=max_history_points)
velocity_x_history_plot = deque(maxlen=max_history_points)
velocity_y_history_plot = deque(maxlen=max_history_points)
position_x_history = deque(maxlen=max_history_points)
position_y_history = deque(maxlen=max_history_points)
correction_vx_history = deque(maxlen=max_history_points)
correction_vy_history = deque(maxlen=max_history_points)
height_history = deque(maxlen=max_history_points)
range_height_history = deque(maxlen=max_history_points)

# Complete trajectory history (never trimmed for data, but downsampled for UI)
MAX_PLOT_TRAJECTORY_POINTS = 5000  # Limit points drawn on 2D plot to prevent lag
complete_trajectory_x = []
complete_trajectory_y = []
key_release_points = []  # Store (x, y) tuples of release points
start_time = None
neo_controller = None
data_lock = threading.Lock()  # Protect shared data structures
# Debug counter for motion callback
debug_counter = 0

# Global logger function - can be set to GUI's log_to_output method
global_logger = None


def set_global_logger(logger_func):
    """Set the global logger function to redirect messages to GUI output window"""
    global global_logger
    global_logger = logger_func


def log_message(message):
    """Log a message using the global logger if available, otherwise print to console"""
    if global_logger is not None:
        try:
            global_logger(message)
        except Exception:
            # Fallback to print if logger fails
            print(message)
    else:
        print(message)


def check_link_safety(cf, logger=None):
    """
    Check if the Crazyflie is still connected and sensor data is fresh.
    Returns True if safe, False otherwise.
    """
    global flight_active, sensor_test_active

    # 1. Connection check
    if not cf.is_connected():
        if logger:
            logger("CRITICAL: Crazyflie disconnected!")
        return False

    # 2. Sensor heartbeat check (only if not in debug mode)
    if not DEBUG_MODE and sensor_data_ready:
        elapsed_since_last_data = time.time() - last_sensor_heartbeat
        if elapsed_since_last_data > DATA_TIMEOUT_THRESHOLD:
            if logger:
                logger(
                    f"CRITICAL: Sensor data timeout! ({elapsed_since_last_data:.2f}s delay)"
                )
            return False

    return True


# === HELPER FUNCTIONS ===
# Inline robust CRTP send + NeoPixel helpers (adapted from neopixel_control.py)
def _send_crtp_with_fallback(cf, port, channel, payload: bytes):
    header = ((port & 0x0F) << 4) | (channel & 0x0F)

    class _PacketObj:
        def __init__(self, header, data: bytes):
            self.header = header
            self.data = data
            try:
                self.datat = tuple(data)
            except Exception:
                self.datat = tuple()

        def is_data_size_valid(self):
            return len(self.data) <= 30

        @property
        def size(self):
            return len(self.data)

        def raw(self):
            return bytes([self.header]) + self.data

    pkt_obj = _PacketObj(header, payload)

    # 1) Crazyflie.send_packet if available
    try:
        send_fn = getattr(cf, "send_packet", None)
        if callable(send_fn):
            try:
                send_fn(pkt_obj)
                return
            except Exception:
                pass
    except Exception:
        pass

    # 2) low-level link object: _link or link
    try:
        link = getattr(cf, "_link", None) or getattr(cf, "link", None)
        if link is not None:
            if hasattr(link, "sendPacket"):
                try:
                    link.sendPacket(pkt_obj)
                    return
                except Exception:
                    pass
            if hasattr(link, "send_packet"):
                try:
                    link.send_packet(pkt_obj)
                    return
                except Exception:
                    pass
    except Exception:
        pass

    # 3) cflib.crtp.send_packet fallback (object or raw bytes)
    try:
        import cflib.crtp as _crtp

        sendp = getattr(_crtp, "send_packet", None)
        if callable(sendp):
            try:
                sendp(pkt_obj)
                return
            except Exception:
                try:
                    sendp(bytes([pkt_obj.header]) + pkt_obj.data)
                    return
                except Exception:
                    pass
    except Exception:
        pass

    raise RuntimeError(
        "Unable to send CRTP packet: no send method available on Crazyflie instance"
    )


# NeoPixel utility wrappers that reuse the same Crazyflie link
def np_set_pixel(cf, index, r, g, b):
    _send_crtp_with_fallback(
        cf, CRTP_PORT_NEOPIXEL, NEOPIXEL_CHANNEL_SET_PIXEL, bytes([index, r, g, b])
    )


def np_show(cf):
    _send_crtp_with_fallback(cf, CRTP_PORT_NEOPIXEL, NEOPIXEL_CHANNEL_SHOW, b"")


def np_clear(cf):
    _send_crtp_with_fallback(cf, CRTP_PORT_NEOPIXEL, NEOPIXEL_CHANNEL_CLEAR, b"")


def np_start_blink(cf, on_ms=500, off_ms=500):
    data = bytes(
        [1, (on_ms >> 8) & 0xFF, on_ms & 0xFF, (off_ms >> 8) & 0xFF, off_ms & 0xFF]
    )
    _send_crtp_with_fallback(cf, CRTP_PORT_NEOPIXEL, NEOPIXEL_CHANNEL_BLINK, data)


def np_stop_blink(cf):
    data = bytes([0, 0, 0, 0, 0])
    _send_crtp_with_fallback(cf, CRTP_PORT_NEOPIXEL, NEOPIXEL_CHANNEL_BLINK, data)


def np_set_all(cf, r, g, b):
    """Set all NeoPixels to same RGB using SET_ALL CRTP channel."""
    # The firmware uses the special broadcast index 0xFF on the SET_PIXEL
    # channel to indicate "set all". That avoids adding a channel value
    # beyond the 2-bit channel field in the CRTP packet.
    _send_crtp_with_fallback(
        cf,
        CRTP_PORT_NEOPIXEL,
        NEOPIXEL_CHANNEL_SET_PIXEL,
        bytes([0xFF, r & 0xFF, g & 0xFF, b & 0xFF]),
    )


def _try_send_with_retries(cf, fn, *args, retries=NP_SEND_RETRIES, logger=None):
    """Call a np_* function with retries and small inter-packet delay.
    fn is expected to be a function taking (cf, *args).
    Returns True on success, False on failure.
    """
    last_exc = None
    fn_name = getattr(fn, "__name__", repr(fn))
    for attempt in range(1, retries + 1):
        try:
            fn(cf, *args)
            return True
        except Exception as e:
            last_exc = e
            if logger:
                logger(f"[NeoPixel] Attempt {attempt} failed: {e}")
            time.sleep(NP_PACKET_DELAY)
    if logger:
        logger(f"[NeoPixel] Failed after {retries} attempts: {last_exc}")
    return False


def calculate_velocity(delta_value, altitude):
    """Convert optical flow delta to linear velocity"""
    if altitude <= 0:
        return 0.0
    if USE_HEIGHT_SCALING:
        # Original height-dependent calculation
        velocity_constant = (5.4 * DEG_TO_RAD) / (30.0 * DT)
        velocity = delta_value * altitude * velocity_constant
    else:
        # Simplified calculation without height dependency
        # Using empirical scaling factor
        velocity = delta_value * OPTICAL_FLOW_SCALE * DT
    return velocity


def smooth_velocity(new_velocity, history):
    """Simple 2-point smoothing filter with adjustable alpha"""
    history[1] = history[0]
    history[0] = new_velocity
    alpha = VELOCITY_SMOOTHING_ALPHA  # Use the global variable
    smoothed = (history[0] * alpha) + (history[1] * (1 - alpha))
    if abs(smoothed) < VELOCITY_THRESHOLD:
        smoothed = 0.0
    return smoothed


def integrate_position(vx, vy, dt):
    """Dead reckoning: integrate velocity to position"""
    global integrated_position_x, integrated_position_y
    if dt <= 0 or dt > 0.1:
        return
    # Simple integration
    integrated_position_x += vx * dt
    integrated_position_y += vy * dt
    # Apply drift compensation when moving slowly
    velocity_magnitude = (vx * vx + vy * vy) ** 0.5
    if velocity_magnitude < VELOCITY_THRESHOLD * 2:
        integrated_position_x -= integrated_position_x * DRIFT_COMPENSATION_RATE * dt
        integrated_position_y -= integrated_position_y * DRIFT_COMPENSATION_RATE * dt
    # Clamp position error
    integrated_position_x = max(
        -MAX_POSITION_ERROR, min(MAX_POSITION_ERROR, integrated_position_x)
    )
    integrated_position_y = max(
        -MAX_POSITION_ERROR, min(MAX_POSITION_ERROR, integrated_position_y)
    )


def periodic_position_reset():
    """Reset integrated position every few seconds"""
    global integrated_position_x, integrated_position_y, last_reset_time
    current_time = time.time()
    if current_time - last_reset_time >= PERIODIC_RESET_INTERVAL:
        integrated_position_x = 0.0
        integrated_position_y = 0.0
        last_reset_time = current_time
        return True
    return False



def apply_firmware_parameters(cf, logger=None):
    """
    Apply custom vertical PID and thrust parameters to the drone's brain.
    Only takes effect if ENABLE_FIRMWARE_PARAMS is True.
    """
    if not ENABLE_FIRMWARE_PARAMS:
        return
        
    try:
        if logger: logger("Applying custom firmware parameters (Z-Axis/Thrust)...")
        # Set parameters as strings since cflib expects that/it's safer for radio transport
        cf.param.set_value('posCtlPid.thrustBase', str(FW_THRUST_BASE))
        cf.param.set_value('posCtlPid.zKp', str(FW_Z_POS_KP))
        cf.param.set_value('velCtlPid.vzKp', str(FW_Z_VEL_KP))
        
        # Brief wait to ensure the drone processed the parameters
        time.sleep(0.2)
        
        # Verify the most important one
        actual_thrust = cf.param.get_value('posCtlPid.thrustBase')
        if logger: logger(f"Firmware configured: thrustBase={actual_thrust}, zKp={FW_Z_POS_KP}, vzKp={FW_Z_VEL_KP}")
        
    except Exception as e:
        if logger: logger(f"WARNING: Failed to set firmware parameters: {str(e)}")


def reset_position_tracking(reset_integrals=True):
    """Reset integrated position tracking to prevent sensor drift"""
    global integrated_position_x, integrated_position_y, last_integration_time, last_reset_time, position_integration_enabled
    global position_integral_x, position_integral_y, velocity_integral_x, velocity_integral_y
    global last_position_error_x, last_position_error_y, last_velocity_error_x, last_velocity_error_y
    global last_sensor_heartbeat
    integrated_position_x = 0.0
    integrated_position_y = 0.0
    last_integration_time = time.time()
    last_sensor_heartbeat = time.time()
    last_reset_time = time.time()
    position_integration_enabled = True
    
    if reset_integrals:
        # Reset PID state - Use this only at the very start of a flight
        position_integral_x = 0.0
        position_integral_y = 0.0
        velocity_integral_x = 0.0
        velocity_integral_y = 0.0
        last_position_error_x = 0.0
        last_position_error_y = 0.0
        last_velocity_error_x = 0.0
        last_velocity_error_y = 0.0
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

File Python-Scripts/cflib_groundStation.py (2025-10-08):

import time
import cflib.crtp
from cflib.crazyflie import Crazyflie
from cflib.crazyflie.log import LogConfig
from cflib.crazyflie.syncCrazyflie import SyncCrazyflie
import tkinter as tk
from matplotlib.backends.backend_tkagg import FigureCanvasTkAgg
from matplotlib.figure import Figure
import matplotlib.animation as animation
import matplotlib.pyplot as plt
import numpy as np

# URI for your LiteWing drone
DRONE_URI = "udp://192.168.43.42"

# Initialize CRTP driverscf
cflib.crtp.init_drivers()

# Shared data dictionary and storage for plotting
log_data = {}
data_history = {param: [] for param in [
    'stateEstimate.pitch', 'stateEstimate.roll', 'stateEstimate.yaw',
    'pwm.m1_pwm', 'pwm.m2_pwm', 'pwm.m3_pwm', 'pwm.m4_pwm',
    'controller.cmd_pitch', 'controller.cmd_roll', 'controller.cmd_yaw',
    'controller.pitchRate', 'controller.rollRate', 'controller.yawRate'
]}
timestamps = []
start_time = None
max_points = 200  # Limit the number of points to keep the plot responsive

# Parameter labels and custom colors
param_labels = {
    'stateEstimate.pitch': 'K_Pitch (deg)',
    'stateEstimate.roll': 'K_Roll (deg)',
    'stateEstimate.yaw': 'K_Yaw (deg)',
    'pwm.m1_pwm': 'M1 (PWM)',
    'pwm.m2_pwm': 'M2 (PWM)',
    'pwm.m3_pwm': 'M3 (PWM)',
    'pwm.m4_pwm': 'M4 (PWM)',
    'controller.cmd_pitch': 'Cmd_Pitch (deg)',
    'controller.cmd_roll': 'Cmd_Roll (deg)',
    'controller.cmd_yaw': 'Cmd_Yaw (deg)',
    'controller.pitchRate': 'D_PitchRate',
    'controller.rollRate': 'D_RollRate',
    'controller.yawRate': 'D_YawRate'
}

# Custom color palette with distinct motor colors
param_colors = {
    'stateEstimate.pitch': 'blue',        # K_Pitch: Blue
    'stateEstimate.roll': 'lightblue',    # K_Roll: Light Blue
    'stateEstimate.yaw': 'darkblue',      # K_Yaw: Dark Blue
    'pwm.m1_pwm': 'green',                # M1: Green
    'pwm.m2_pwm': 'orange',               # M2: Orange
    'pwm.m3_pwm': 'teal',                 # M3: Teal
    'pwm.m4_pwm': 'saddlebrown',          # M4: Brown
    'controller.cmd_pitch': 'red',        # Cmd_Pitch: Red
    'controller.cmd_roll': 'lightcoral',  # Cmd_Roll: Light Coral
    'controller.cmd_yaw': 'darkred',      # Cmd_Yaw: Dark Red
    'controller.pitchRate': 'purple',     # D_PitchRate: Purple
    'controller.rollRate': 'violet',      # D_RollRate: Violet
    'controller.yawRate': 'darkviolet'    # D_YawRate: Dark Violet
}

class DroneLoggerUI:
    def __init__(self, root):
        self.root = root
        self.root.title("Drone Parameter Logger")
        self.cf = Crazyflie(rw_cache='./cache')
        self.scf = None
        self.logging_active = False
        self.paused = False
        self.anim = None

        # Connect to drone and arm it on launch
        try:
            self.scf = SyncCrazyflie(DRONE_URI, cf=self.cf)
            self.scf.__enter__()
            print("Connecting to drone...")
            time.sleep(2.0)
            # Arm the drone with zero setpoint
            print("Arming drone with zero thrust...")
            self.cf.commander.send_setpoint(0, 0, 0, 0)  # roll, pitch, yaw, thrust
            time.sleep(0.1)
        except Exception as e:
            print(f"Error connecting to drone: {e}")
            self.on_closing()

        # UI Elements
        # Battery display label
        self.battery_var = tk.StringVar(value="Battery: N/A V")
        self.battery_label = tk.Label(root, textvariable=self.battery_var)
        self.battery_label.pack(anchor='ne')  # Top-right corner

        self.start_button = tk.Button(root, text="Start", command=self.start_logging)
        self.start_button.pack()

        self.pause_button = tk.Button(root, text="Pause", command=self.toggle_pause, state=tk.DISABLED)
        self.pause_button.pack()

        # Thrust slider
        self.thrust_var = tk.IntVar(value=0)
        self.thrust_slider = tk.Scale(root, from_=0, to=60000, orient=tk.HORIZONTAL, label="Thrust", variable=self.thrust_var, length=300)
        self.thrust_slider.pack()

        # Checkboxes for selecting parameters to plot
        self.plot_vars = {}
        checkbox_frame = tk.Frame(root)
        checkbox_frame.pack()
        for param, label in param_labels.items():
            var = tk.BooleanVar(value=True)  # Default to True (all plotted)
            self.plot_vars[param] = var
            tk.Checkbutton(checkbox_frame, text=label, variable=var).pack(side=tk.LEFT)
            # Bind callback to update plot visibility when checkbox changes
            var.trace_add("write", lambda *args, p=param: self.update_plot_visibility(p))

        # Matplotlib figure
        self.fig = Figure(figsize=(10, 5))
        self.ax = self.fig.add_subplot(111)
        self.ax.set_xlabel("Time (s)")
        self.ax.set_ylabel("Value")
        self.lines = {param: self.ax.plot([], [], label=label, color=param_colors[param])[0] for param, label in param_labels.items()}
        self.ax.legend(bbox_to_anchor=(1.05, 1), loc='upper left', fontsize='small')
        self.ax.grid(True)
        self.fig.subplots_adjust(right=0.75)  # Make space for the legend

        # Embed plot in Tkinter
        self.canvas = FigureCanvasTkAgg(self.fig, master=root)
        self.canvas.get_tk_widget().pack()

        # LogConfigs
        self.log_battery_state = LogConfig(name="BatteryState", period_in_ms=50)
        self.log_battery_state.add_variable('pm.vbat', 'float')
        self.log_battery_state.add_variable('stateEstimate.pitch', 'float')
        self.log_battery_state.add_variable('stateEstimate.roll', 'float')
        self.log_battery_state.add_variable('stateEstimate.yaw', 'float')

        self.log_motor = LogConfig(name="Motor", period_in_ms=50)
        self.log_motor.add_variable('pwm.m1_pwm', 'uint32_t')
        self.log_motor.add_variable('pwm.m2_pwm', 'uint32_t')
        self.log_motor.add_variable('pwm.m3_pwm', 'uint32_t')
        self.log_motor.add_variable('pwm.m4_pwm', 'uint32_t')

        self.log_controller = LogConfig(name="Controller", period_in_ms=50)
        self.log_controller.add_variable('controller.cmd_pitch', 'float')
        self.log_controller.add_variable('controller.cmd_roll', 'float')
        self.log_controller.add_variable('controller.cmd_yaw', 'float')
        self.log_controller.add_variable('controller.pitchRate', 'float')
        self.log_controller.add_variable('controller.rollRate', 'float')
        self.log_controller.add_variable('controller.yawRate', 'float')

        # Set up callbacks
        self.log_battery_state.data_received_cb.add_callback(self.battery_state_callback)
        self.log_motor.data_received_cb.add_callback(self.motor_callback)
        self.log_controller.data_received_cb.add_callback(self.controller_callback)
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
